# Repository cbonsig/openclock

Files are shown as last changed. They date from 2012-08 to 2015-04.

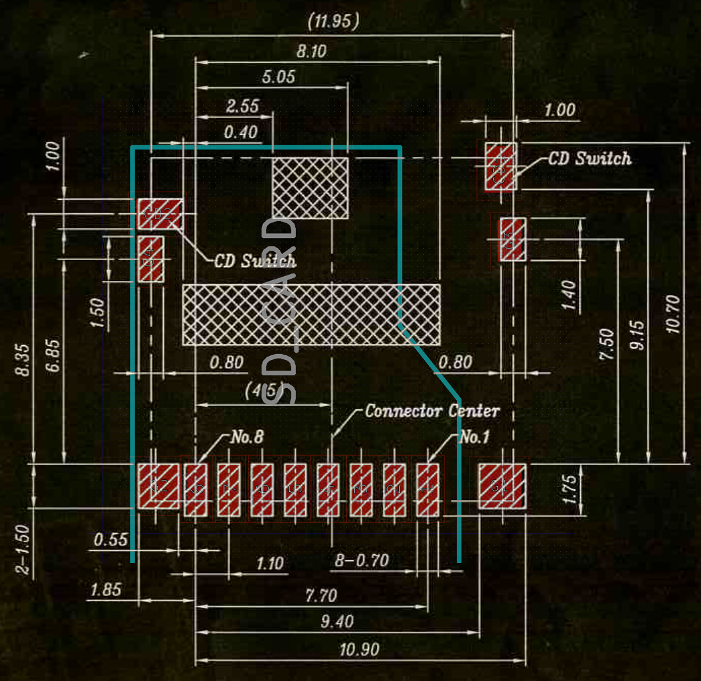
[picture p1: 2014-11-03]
kicad/Datasheets/U5 uSD_overlay.png

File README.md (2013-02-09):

openclock
=========

A clock designed to resolve the flaws of every annoying alarm clock that I've ever owned. Large display that can be easily read with uncorrected vision, adaptive brightness based on the time of day, intuitive touchscreen interface, clear feedback on the state of the alarm, intelligent alarm audio. Powered by Arduino. A work in progress. Journal of effort to date at http://clock.bonsignore.com

Open Clock Project by Craig Bonsignore is licensed under a Creative Commons Attribution-ShareAlike 3.0 United States License.Based on a work at http://clock.bonsignore.com.

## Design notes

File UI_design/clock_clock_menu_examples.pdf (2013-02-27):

P | M | A M | P | M | P M | 7: 0 | 0 | A | P | M | P | M | P | M | P | M
S U N | F E B | S U N | F E | B | S U N | F | E | B | S | U | N | F | E | B | S | U | N | F | E | B | S | U | N | F | E | B | S | U | N | F | E | B | S | U | N | F | E | B
P M | A M | A L A R M | A | M | A | L | A | R | M | A | M | A | L | A | R | M | A | M | A | L | A | R | M | A | M | A | L | A | R | M | A | M | A | L | A | R | M | A | M
5: 3 0 A | P | M | D | O | N | E | A | M | A | L | A | R | M | O | N | A | L | A | R | M | O | F | F | A | L | A | R | M | O | F | F | A | L | A | R | M | O | F | F
D | O | N | E | A | M | A | L | A | R | M | O | F | F | A | L | A | R | M | O | N | T | I | M | E | P | M | T | I | M | E | P | M
7: 0 | 0 | A | P | M | P | M | 7 | 0 | 0 | A | P | M | D | O | N | E | P | M | Y | E | A | R
P | M | M | O | N | T | H
D | O | N | E | D | A | Y

P M

open%clock%menu%examples%2013.02.26

the%alarm%time%is%
displayed%at%the%bottom%
left%whenever%the%alarm%
is%ON.%current%time%and%
alarm%time%are%clearly%
displayed,%so%it%is%
obvious%when%the%alarm%
is%set%correctly%(or%
incorrectly!)

let's%assume%you
probably%want%it
turned%on.%so%in%this
case,%alarm%is%changed
from%OFF%to%ON.

7: 0 0

⬇%tap%"done"

⬇%time%out
1 0: 4 4

if%you%bother%to

case%2:%check%alarm
1 0: 4 4

⬇%tap%screen
2 4

⬇%tap%screen%again
5: 3 0

2 4

⬇%time%out
1 0: 4 4

case%1:%show%date%(nite)
1 0: 4 4

⬇%tap%screen
2 4 | 2 4

check%the%alarm,%

a%single%tap%will%switch%
to%the%date%display,%
then%revert%to%the%time%
after%a%few%seconds.
2 4 | 2 4

case%2:%show%date%(day)
9: 2 0

⬇%tap%screen

1 0: 4 5

⬇%tap%screen | ⬇%tap%screen | ⬇%tap%screen | ⬇%tap%screen | ⬇%tap%screen

⬇"tap%"month"
2 4

⬇"tap%"done"

2 0 1 3

⬇"tap%"year"
0 2

⬇"tap%"alarm"
1 0: 4 4

⬇"tap%"time"

7: 0 0

⬇"tap%"alarm"
7: 0 0

case%7:%set%date
1 0: 4 4

⬇%tap%screen%again

2 4

1 1: 4 4

⬇"tap%"done"
1 1: 4 4

case%6:%set%time
1 0: 4 4

⬇%tap%screen%again

2 4

7: 0 0

⬇"tap%"alarm"
7: 0 0

1 0: 4 5

⬇"tap%"alarm"
1 0: 4 4

⬇"tap%digits

⬇"tap%"off"
7: 0 0

⬇"any%other%tap%/%timeout

7: 0 0

⬇"tap%"alarm"
7: 0 0

1 0: 4 5

case%5:%toggle%alarm%on
1 0: 4 4

⬇%tap%screen%again

⬇"tap%"on"
7: 0 0

⬇"any%other%tap%/%timeout

7: 0 0

⬇"tap%"alarm"
7: 0 0

case%4:%toggle%alarm%off
1 0: 4 4
⬇%time%out | ⬇%tap%screen%again
9: 2 0

from%7:00am%to%6:59pm%
("day"),%the%digits%are%
green.%from%7:00pm%to%
6:59am%("nite"),%the%
digits%are%red.%alarm%
digits%follow%the%same%
convention.

1 0: 4 5

after%first%digit%is%
tapped,%"alarm"%changes%
to%"done".%after%
clicking%"done",%turn%
alarm%ON,%and%return%to%
time%display.

In%alarm%set%mode,%
tapping%the%message%area%
instead%of%the%digits%
advances%to%toggle%mode.%
the%display%shows%"on"%
in%this%case.%touching%
"on"%toggles%alarm%to%
"off".%tapping%"off"%
will%toggle%back%to%
"on",%while%tapping%
anything%else%returns%to%
normal%time%display.

case%3:%set%alarm

In%alarm%toggle%mode,%
tapping%"alarm"%advances%
to%the%time%set%mode.%
this%behaves%the%same%as%
alarm%set,%where%"time"%
changes%to%"done"%when%
the%first%digit%is%
tapped.

shortcut:%in%normal%time%
display,%tap%the%alarm%
time%in%the%lower%left%
to%toggle%the%alarm%off.

Similar%behavior%for%
case%where%alarm%state%
is%initially%off.

shortcut:%in%normal%time%
display,%tap%the%empty%
spot%in%the%lower%left%
to%toggle%the%alarm%on.

The%date%is%set%using%a%
similar%approach.%The%
new%date%is%not%
committed%until%"done"%
is%tapped%on%the%final%
(day)%screen.

⬇%tap%digits%to%set

1 0: 4 4

⬇%tap%screen%again
5: 3 0

5: 3 1

⬇%first%tap%of%digit

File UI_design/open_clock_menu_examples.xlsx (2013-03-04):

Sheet: Feb26
case 1: show date (nite) |  |  |  |  |  |  | case 2: show date (day) |  |  |  |  |  |  | case 2: check alarm |  |  |  |  |  |  |  | case 3: set alarm |  |  |  |  |  |  |  | case 4: toggle alarm off |  |  |  |  |  |  |  | case 5: toggle alarm on |  |  |  |  |  |  |  | case 6: set time
1 |  | 0: | 4 |  | 4 |  |  |  | 9: | 2 |  | 0 |  | 1 |  | 0: |  | 4 |  | 4 |  | 1 |  | 0: |  | 4 |  | 4 |  | 1 |  | 0: |  | 4 |  | 4 |  | 1 |  | 0: |  | 4 |  | 4 |  | 1 |  | 0: |  | 4
 |  |  |  |  | P | M |  |  |  |  |  | A | M |  |  |  |  |  |  | P | M |  |  |  |  |  |  | P | M |  | 7: | 0 | 0 | A |  | P | M |  |  |  |  |  |  | P | M
⬇ tap screen |  |  |  |  |  |  | ⬇ tap screen |  |  |  |  |  |  | ⬇ tap screen |  |  |  |  |  |  |  | ⬇ tap screen |  |  |  |  |  |  |  | ⬇ tap screen |  |  |  |  |  |  |  | ⬇ tap screen |  |  |  |  |  |  |  | ⬇ tap screen
 |  |  | 2 |  | 4 |  |  |  |  | 2 |  | 4 |  |  |  |  |  | 2 |  | 4 |  |  |  |  |  | 2 |  | 4 |  |  |  |  |  | 2 |  | 4 |  |  |  |  |  | 2 |  | 4 |  |  |  |  |  | 2
S | U | N |  | F | E | B | S | U | N |  | F | E | B | S | U | N |  |  | F | E | B | S | U | N |  |  | F | E | B | S | U | N |  |  | F | E | B | S | U | N |  |  | F | E | B | S | U | N
⬇ time out |  |  |  |  |  |  | ⬇ time out |  |  |  |  |  |  | ⬇ tap screen again |  |  |  |  |  |  |  | ⬇ tap screen again |  |  |  |  |  |  |  | ⬇ tap screen again |  |  |  |  |  |  |  | ⬇ tap screen again |  |  |  |  |  |  |  | ⬇ tap screen again
1 |  | 0: | 4 |  | 4 |  |  |  | 9: | 2 |  | 0 |  |  |  | 5: |  | 3 |  | 0 |  |  |  | 5: |  | 3 |  | 0 |  |  |  | 7: |  | 0 |  | 0 |  |  |  | 7: |  | 0 |  | 0 |  |  |  | 7: |  | 0
 |  |  |  |  | P | M |  |  |  |  |  | A | M | A | L | A | R | M |  | A | M | A | L | A | R | M |  | A | M | A | L | A | R | M |  | A | M | A | L | A | R | M |  | A | M | A | L | A | R | M
a single tap will switch to the date display, then revert to the time after a few seconds. |  |  |  |  |  |  | from 7:00am to 6:59pm ("day"), the digits are green. from 7:00pm to 6:59am ("nite"), the digits are red. alarm digits follow the same convention. |  |  |  |  |  |  | ⬇ time out |  |  |  |  |  |  |  | ⬇ first tap of digit |  |  |  |  |  |  |  | ⬇ tap "alarm" |  |  |  |  |  |  |  | ⬇ tap "alarm" |  |  |  |  |  |  |  | ⬇ tap "alarm"
 |  |  |  |  |  |  |  |  |  |  |  |  |  | 1 |  | 0: |  | 4 |  | 4 |  |  |  | 5: |  | 3 |  | 1 |  |  |  | 7: |  | 0 |  | 0 |  |  |  | 7: |  | 0 |  | 0 |  |  |  | 7: |  | 0
 |  |  |  |  |  |  |  |  |  |  |  |  |  |  | 5: | 3 | 0 | A |  | P | M | D | O | N | E |  |  | A | M | A | L | A | R | M |  | O | N | A | L | A | R | M | O | F | F | A | L | A | R | M
 |  |  |  |  |  |  |  |  |  |  |  |  |  | if you bother to |  |  |  |  |  |  |  | ⬇ tap digits to set |  |  |  |  |  |  |  | ⬇ tap "on" |  |  |  |  |  |  |  | ⬇ tap "off" |  |  |  |  |  |  |  | ⬇ tap "alarm"
 |  |  |  |  |  |  |  |  |  |  |  |  |  | check the alarm,
 |  |  |  |  |  |  |  |  |  |  |  |  |  | let's assume you |  |  |  |  |  |  |  |  |  | 7: |  | 0 |  | 0 |  |  |  | 7: |  | 0 |  | 0 |  |  |  | 7: |  | 0 |  | 0 |  | 1 |  | 0: |  | 4
 |  |  |  |  |  |  |  |  |  |  |  |  |  | probably want it
 |  |  |  |  |  |  |  |  |  |  |  |  |  | turned on. so in this
 |  |  |  |  |  |  |  |  |  |  |  |  |  | case, alarm is changed |  |  |  |  |  |  |  | D | O | N | E |  |  | A | M | A | L | A | R | M | O | F | F | A | L | A | R | M |  | O | N | T | I | M | E
 |  |  |  |  |  |  |  |  |  |  |  |  |  | from OFF to ON.
 |  |  |  |  |  |  |  |  |  |  |  |  |  |  |  |  |  |  |  |  |  | ⬇ tap "done" |  |  |  |  |  |  |  | ⬇ any other tap / timeout |  |  |  |  |  |  |  | ⬇ any other tap / timeout |  |  |  |  |  |  |  | ⬇ tap digits
 |  |  |  |  |  |  |  |  |  |  |  |  |  | the alarm time is displayed at the bottom left whenever the alarm is ON. current time and alarm time are clearly displayed, so it is obvious when the alarm is set correctly (or incorrectly!)
 |  |  |  |  |  |  |  |  |  |  |  |  |  |  |  |  |  |  |  |  |  | 1 |  | 0: |  | 4 |  | 5 |  | 1 |  | 0: |  | 4 |  | 5 |  | 1 |  | 0: |  | 4 |  | 5 |  | 1 |  | 1: |  | 4
 |  |  |  |  |  |  |  |  |  |  |  |  |  |  |  |  |  |  |  |  |  |  | 7: | 0 | 0 | A |  | P | M |  |  |  |  |  |  | P | M |  | 7: | 0 | 0 | A |  | P | M | D | O | N | E
 |  |  |  |  |  |  |  |  |  |  |  |  |  |  |  |  |  |  |  |  |  | after first digit is tapped, "alarm" changes to "done". after clicking "done", turn alarm ON, and return to time display. |  |  |  |  |  |  |  | In alarm set mode, tapping the message area instead of the digits advances to toggle mode. the display shows "on" in this case. touching "on" toggles alarm to "off". tapping "off" will toggle back to "on", while tapping anything else returns to normal time display. |  |  |  |  |  |  |  | Similar behavior for case where alarm state is initially off. |  |  |  |  |  |  |  | ⬇ tap "done"
 |  |  |  |  |  |  |  |  |  |  |  |  |  |  |  |  |  |  |  |  |  |  |  |  |  |  |  |  |  |  |  |  |  |  |  |  |  |  |  |  |  |  |  |  |  | 1 |  | 1: |  | 4
 |  |  |  |  |  |  |  |  |  |  |  |  |  |  |  |  |  |  |  |  |  |  |  |  |  |  |  |  |  |  |  |  |  |  |  |  |  | shortcut: in normal time display, tap the empty spot in the lower left to toggle the alarm on.
 |  |  |  |  |  |  |  |  |  |  |  |  |  |  |  |  |  |  |  |  |  |  |  |  |  |  |  |  |  |  |  |  |  |  |  |  |  |  |  |  |  |  |  |  |  | In alarm toggle mode, tapping "alarm" advances to the time set mode. this behaves the same as alarm set, where "time" changes to "done" when the first digit is tapped.
 |  |  |  |  |  |  |  |  |  |  |  |  |  |  |  |  |  |  |  |  |  |  |  |  |  |  |  |  |  | shortcut: in normal time display, tap the alarm time in the lower left to toggle the alarm off.
open clock menu examples 2013.02.26

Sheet: Mar3
0 | 1 |  | 0: |  | 4 |  | 4
 |  |  |  |  |  |  | P | M
 | ⬇ tap screen
10 |  |  |  |  | 2 |  | 4
 | S | U | N |  |  | F | E | B
 | ⬇ tap screen
20 | < |  |  |  |  |  | > |  | 201 |  |  | 7: |  | 0 |  | 0 |  | 0 | 1 |  | 0: |  | 4 | 4
 | A | L | A | R | M | S | E | T |  | D | O | N | E |  |  | A | M |  |  | 5: | 3 | 0 | A | P | M
 | ⬇ tap >
30 | < |  |  |  |  |  | > |  | 40 | < |  |  |  |  |  | >
 | S | O | U | N | D | O | F | F |  | S | O | U | N | D |  | O | N |  |  |  |  |  |  |  |  |  |  | change code for this new menu scheme
 |  |  |  |  |  |  |  |  |  |  |  |  |  |  |  |  |  |  |  |  |  |  |  |  |  |  |  | change display/render scheme to allow for non-digits in hr/min area
 | ⬇ tap >
40 | < |  |  |  |  |  | > |  | 30 | < |  |  |  |  |  | >
 | S | O | U | N | D |  | O | N |  | S | O | U | N | D | O | F | F
 | ⬇ tap >
50 | < |  |  |  |  |  | > |  | 501 | 1 |  | 1: |  | 4 |  | 5 |  | 0 | 1 |  | 1: |  | 4 | 5
 | T | I | M | E |  | S | E | T |  | D | O | N | E |  |  | P | M |  |  |  |  |  |  | P | M
 | ⬇ tap >
60 | < |  |  |  |  |  | > |  | 601 | 2 |  | 0 |  | 1 |  | 3 |  | 602 |  |  |  |  | 0 | 3 |  | 603 |  |  |  | 0 |  | 4 |  | 0 | 1 | 0: | 4 | 4
 | D | A | T | E |  | S | E | T |  | Y | E | A | R |  |  | > | > |  | M | O | N | T | H | > | > |  | D | A | Y | D | O | N | E |  |  |  |  | P | M
 | ⬇ tap >
99 | < |  |  |  |  |  | >
 | E | X | I | T
 | ⬇ tap >
0 | 1 |  | 0: |  | 4 |  | 4
 |  |  |  |  |  |  | P | M
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

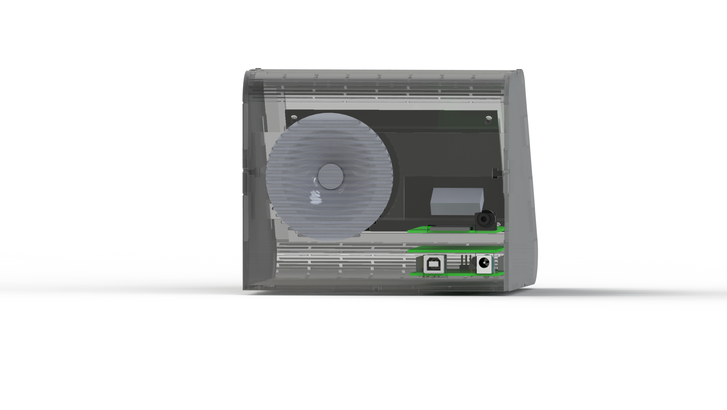
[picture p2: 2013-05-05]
enclosure_design/2D_rev2/clear_rendered_back.png

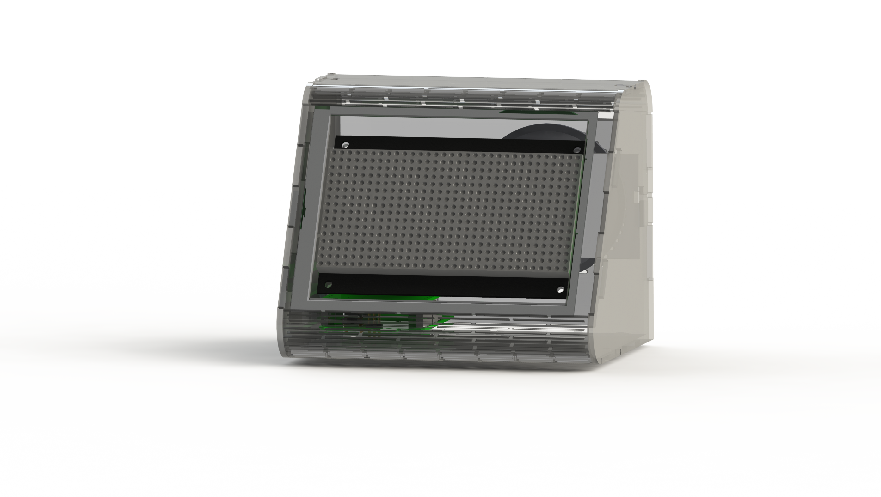
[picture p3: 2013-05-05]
enclosure_design/2D_rev2/clear_rendered.png

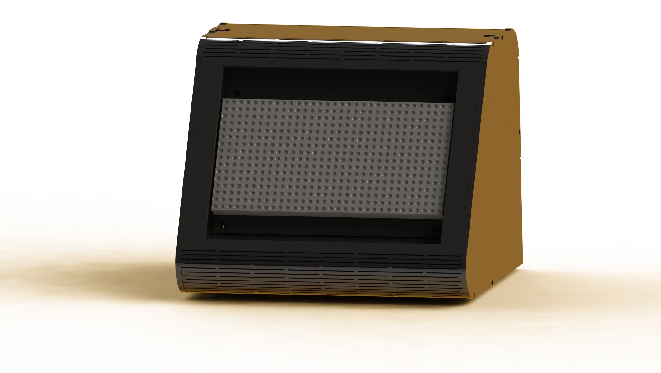
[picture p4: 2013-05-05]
enclosure_design/2D_rev2/black_rendered_front.png

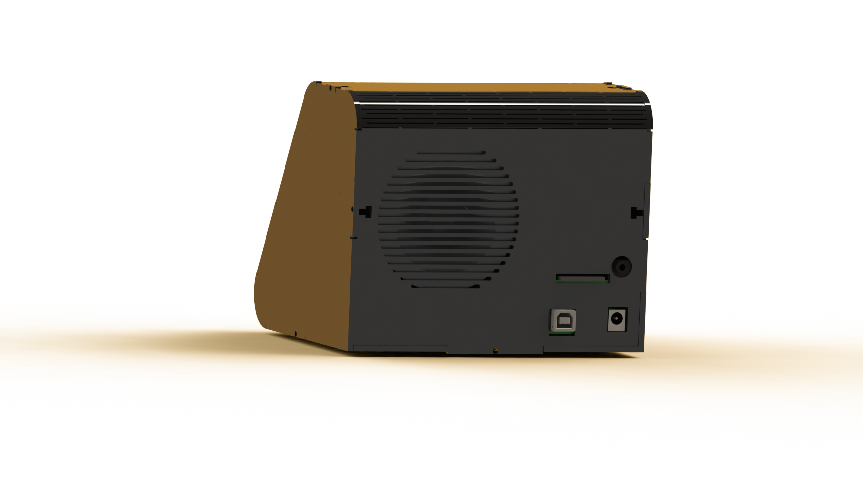
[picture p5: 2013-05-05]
enclosure_design/2D_rev2/black_rendered_back.png

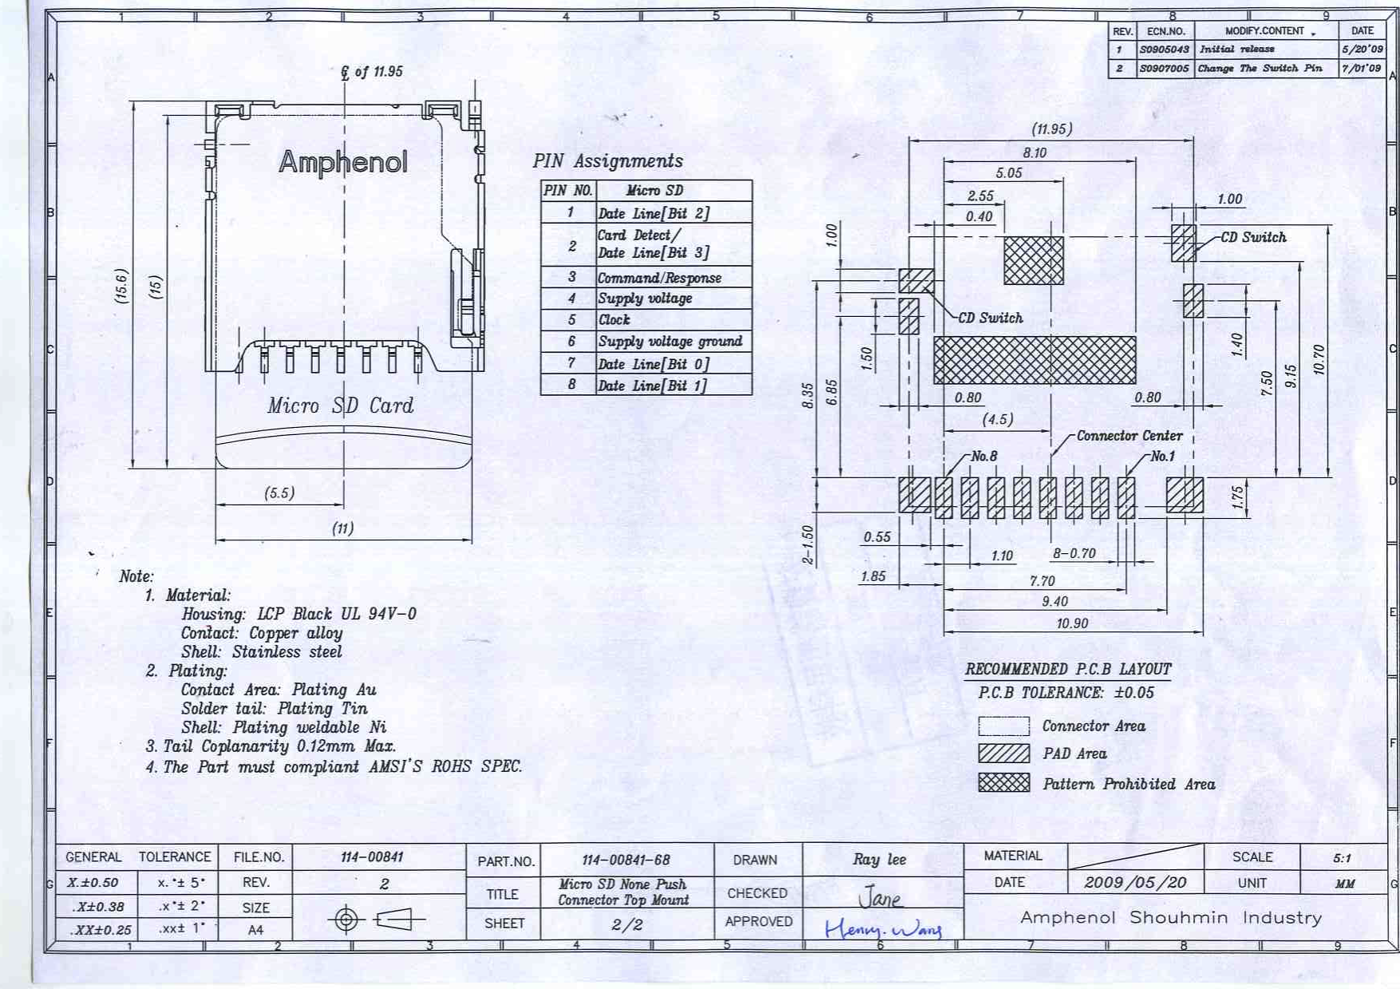
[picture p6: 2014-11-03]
kicad/Datasheets/U5 114-00841-68 uSD.png

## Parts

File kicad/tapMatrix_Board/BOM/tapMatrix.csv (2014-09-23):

Id | Designator | Package | Quantity | Designation | Supplier and ref
1 | C1,C2,C3,C5,C7 | Capacitors_SMD:c_0603 | 5 | 0.1uF
2 | C8 | Capacitors_SMD:c_0603 | 1 | 0.01uF
3 | IC1 | Housings_SOIC:SOIC-8_N | 1 | DS1307
4 | JP1 | Pin_Headers:Pin_Header_Straight_1x06 | 1 | 6_PIN_1
5 | JP2 | Pin_Headers:Pin_Header_Straight_1x06 | 1 | 6_PIN_2
6 | JP3 | Pin_Headers:Pin_Header_Straight_1x08 | 1 | 8_PIN_1
7 | JP4 | Pin_Headers:Pin_Header_Straight_1x08 | 1 | 8_PIN_2
8 | JP6 | Pin_Headers:Pin_Header_Straight_1x02 | 1 | SPKR
9 | R1,R2 | Resistors_SMD:R_0603 | 2 | R
10 | R3 | Resistors_SMD:R_0603 | 1 | 100K
11 | R4 | Resistors_SMD:R_0603 | 1 | 1.5K
12 | R5 | Resistors_SMD:R_0603 | 1 | 10K
13 | U2 | SMD_Packages:SOIC-8-N | 1 | MCP4921-E/SN
14 | BT1 | tapmatrix:CR2032 | 1 | BATTERY
15 | P6 | tapmatrix:5103310--3 | 1 | LED_MATRIX_HDR
16 | P5 | tapmatrix:SFW4R-5STE1LF | 1 | TS_ZIF
17 | U5 | tapmatrix:114-00841-68 | 1 | SD_CARD
18 | C4,C6,C9 | Capacitors_Tantalum_SMD:TantalC_SizeC_EIA-6032_Reflow | 3 | 100uF/6V
19 | JP5 | Pin_Headers:Pin_Header_Straight_1x04 | 1 | 4_PIN_1
20 | U3 | SMD_Packages:SOIC-14_N | 1 | 74LS125
21 | U1 | Housings_SOT-89:SOT89-3_Housing | 1 | MCP1700T-3302E/MB
22 | U4 | Housings_SOIC:SOIC-8_N | 1 | TL072

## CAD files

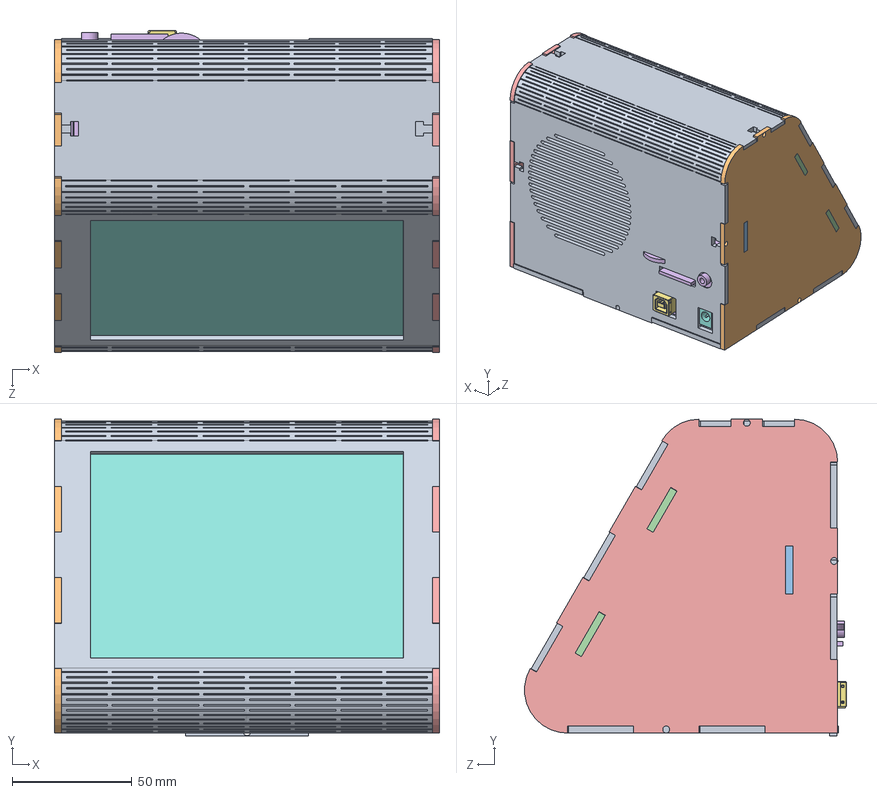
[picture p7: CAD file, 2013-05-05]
enclosure_design/2D_rev2/Enclosure_Assembly.SLDASM
161.0 x 132.4 x 134.5 mm
Combine1
Cut-Extrude24
uno-pcb x 2
SW3dPS-67068-0000-molex
RAPC732
3x2-100 x 2
C-0534237-04-3 x 2
C-0534237-06-3 x 2
28pdipskt
User Library-28 pin dip
wave_shield
SureElectronics_32x16_DE-DP14112
Fujitsu_4wire_6.4in_N010-0554-T048
3in_speaker

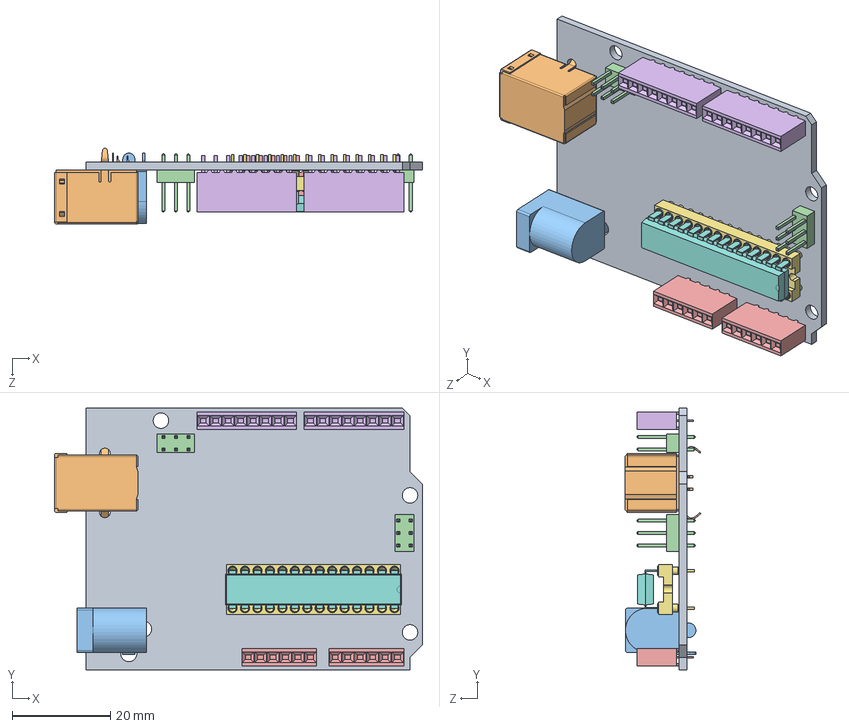
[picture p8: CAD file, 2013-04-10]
enclosure_design/2D_rev2/uno-assy/uno-assy.SLDASM
75.0 x 53.3 x 15.4 mm
uno-pcb
SW3dPS-67068-0000-molex
RAPC732
3x2-100 x 2
C-0534237-04-3 x 2
C-0534237-06-3 x 2
28pdipskt
User Library-28 pin dip

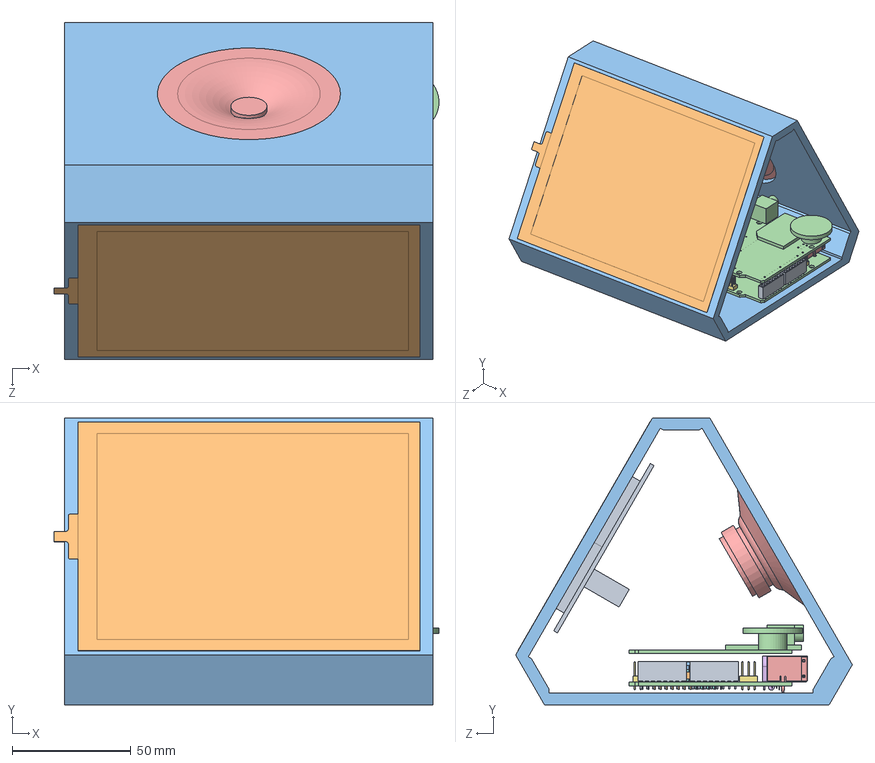
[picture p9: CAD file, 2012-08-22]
enclosure_design/3D_rev1/Open_Clock.SLDASM
161.9 x 120.6 x 141.6 mm
SureElectronics_32x16_DE-DP14112
Fujitsu_4wire_6.4in_N010-0554-T048
base
uno-pcb
SW3dPS-67068-0000-molex
RAPC732
3x2-100 x 2
C-0534237-04-3 x 2
C-0534237-06-3 x 2
28pdipskt
User Library-28 pin dip
wave_shield
3in_speaker

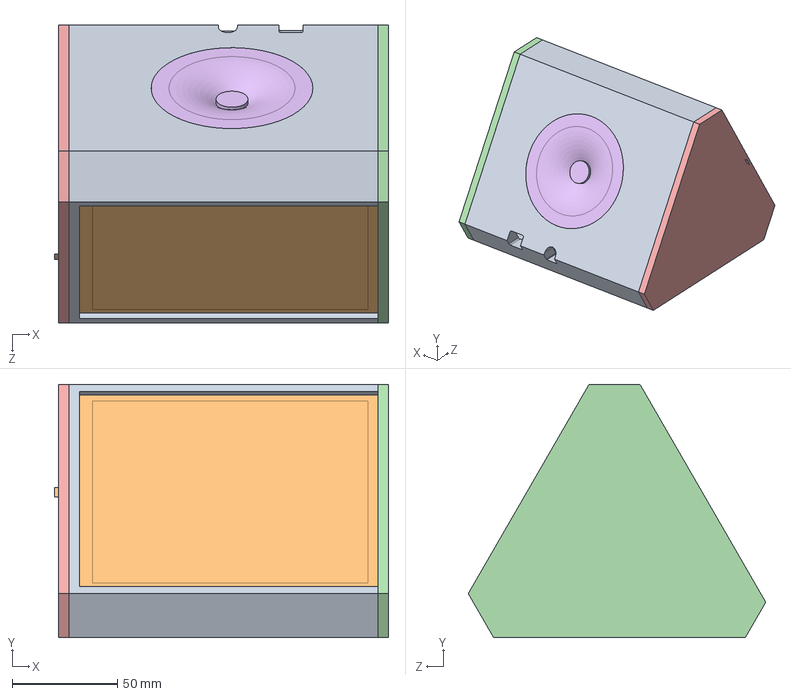
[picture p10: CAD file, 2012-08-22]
enclosure_design/3D_rev1/Open_Clock_2.SLDASM
159.0 x 120.6 x 141.6 mm
base_plus_walls
Fujitsu_4wire_6.4in_N010-0554-T048
SureElectronics_32x16_DE-DP14112
right_cap
left_cap
uno-pcb
SW3dPS-67068-0000-molex
RAPC732
3x2-100 x 2
C-0534237-04-3 x 2
C-0534237-06-3 x 2
28pdipskt
User Library-28 pin dip
3in_speaker
wave_shield

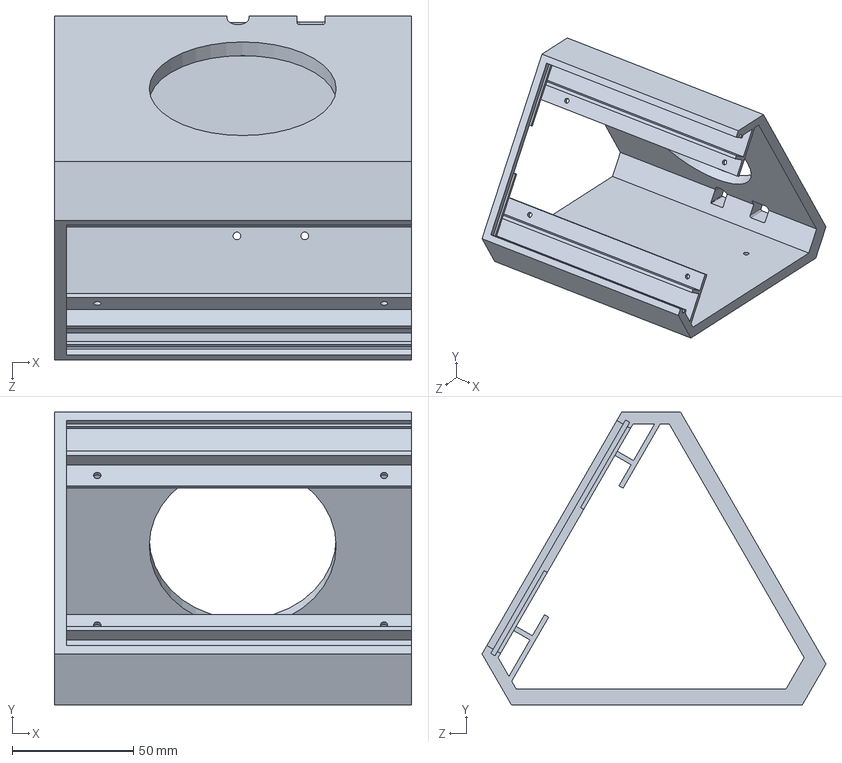
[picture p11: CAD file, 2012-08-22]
enclosure_design/3D_rev1/base_plus_walls.SLDPRT
147.0 x 120.6 x 141.6 mm

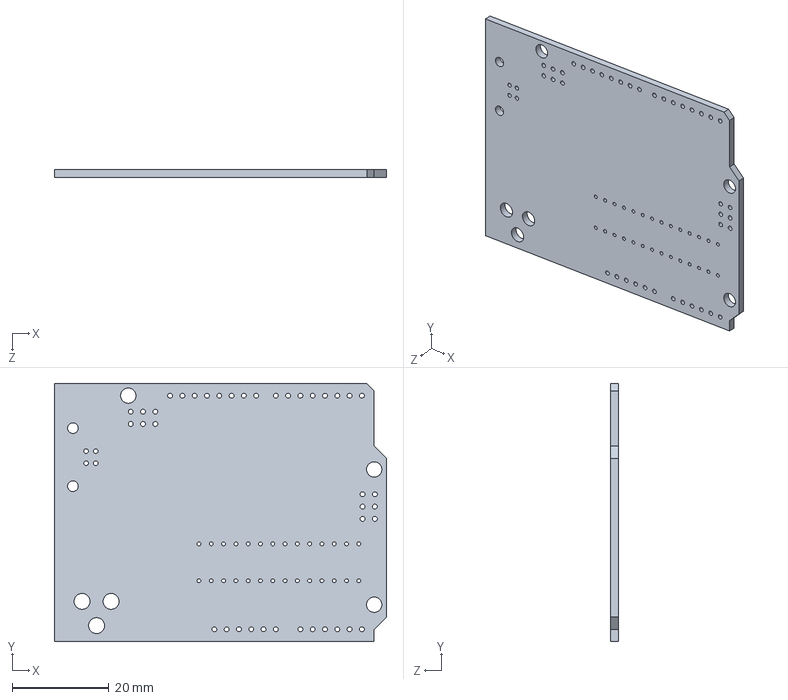
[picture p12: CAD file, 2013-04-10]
enclosure_design/2D_rev2/uno-assy/uno-pcb.SLDPRT
68.6 x 53.3 x 1.59 mm

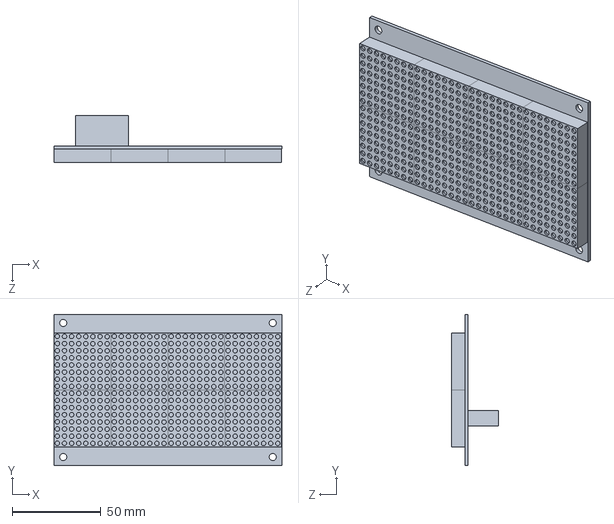
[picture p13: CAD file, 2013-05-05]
enclosure_design/2D_rev2/SureElectronics_32x16_DE-DP14112.SLDPRT
128.3 x 85.1 x 26.3 mm

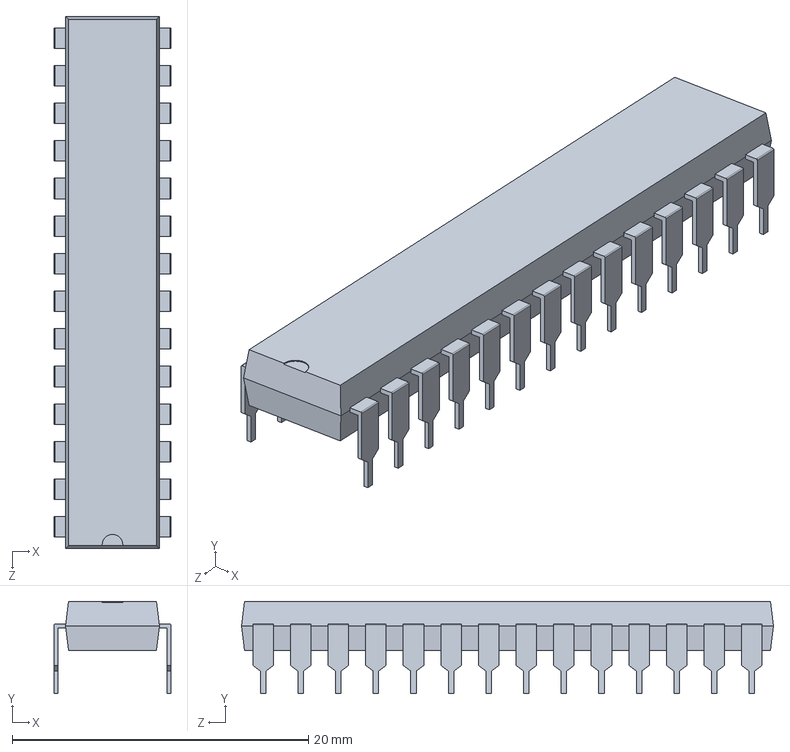
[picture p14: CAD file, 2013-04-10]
enclosure_design/2D_rev2/uno-assy/User Library-28 pin dip.SLDPRT
7.87 x 6.22 x 35.9 mm

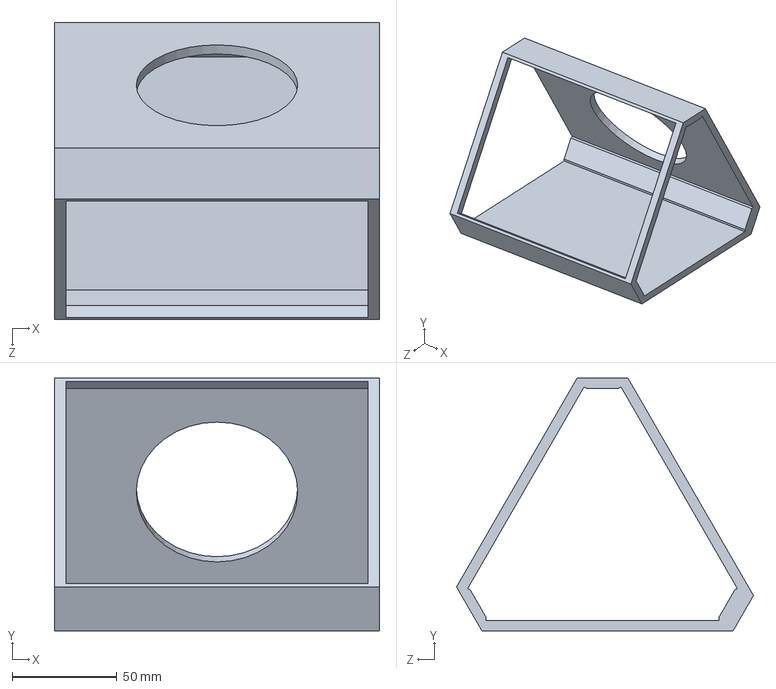
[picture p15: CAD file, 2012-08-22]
enclosure_design/3D_rev1/base.SLDPRT
155.0 x 120.6 x 141.6 mm

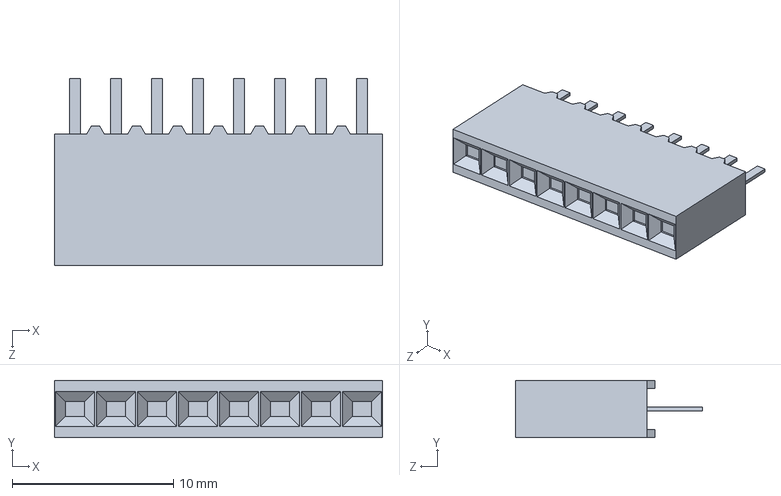
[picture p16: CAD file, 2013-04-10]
enclosure_design/2D_rev2/uno-assy/C-0534237-06-3.SLDPRT
20.3 x 3.56 x 11.6 mm

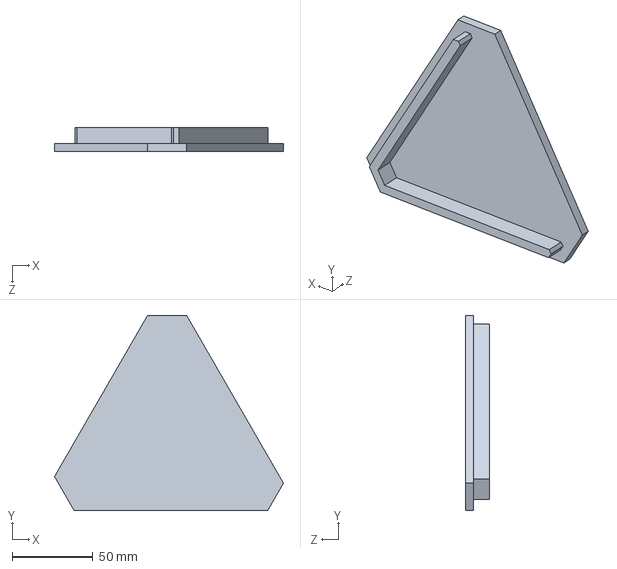
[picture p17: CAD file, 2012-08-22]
enclosure_design/3D_rev1/right_cap.sldprt
141.6 x 120.6 x 15.0 mm

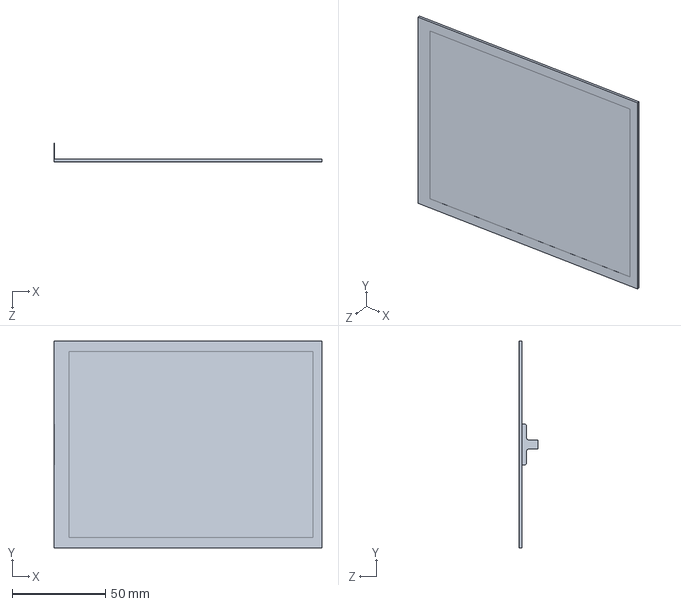
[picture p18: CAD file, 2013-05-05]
enclosure_design/2D_rev2/Fujitsu_4wire_6.4in_N010-0554-T048.SLDPRT
144.0 x 111.0 x 10.0 mm

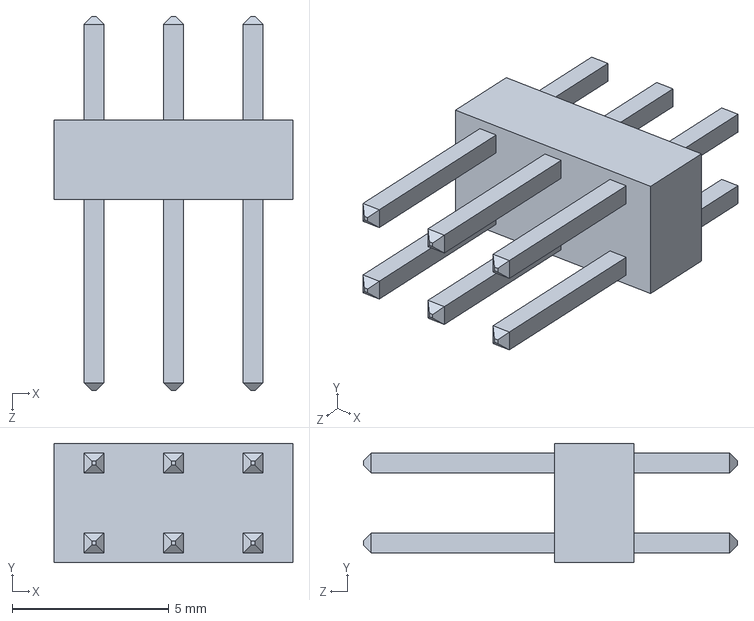
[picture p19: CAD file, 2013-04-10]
enclosure_design/2D_rev2/uno-assy/3x2-100.SLDPRT
7.62 x 3.81 x 11.9 mm

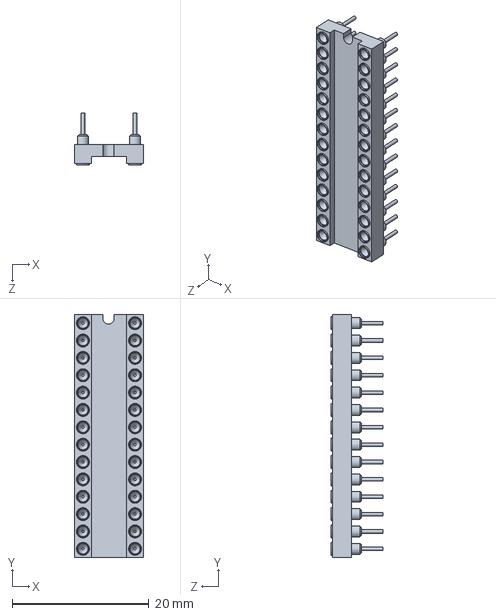
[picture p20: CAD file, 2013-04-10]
enclosure_design/2D_rev2/uno-assy/28pdipskt.SLDPRT
10.2 x 35.6 x 7.62 mm

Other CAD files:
enclosure_design/2D_rev2/Body4.sldprt
enclosure_design/2D_rev2/Cut-Extrude24.sldprt
enclosure_design/3D_rev1/left_cap.sldprt
enclosure_design/2D_rev2/Body5.sldprt
enclosure_design/2D_rev1/Fujitsu_4wire_6.4in_N010-0554-T048.SLDPRT
enclosure_design/2D_rev1/SureElectronics_32x16_DE-DP14112.SLDPRT
enclosure_design/2D_rev1/box1-1-bottom.sldprt
enclosure_design/2D_rev1/box1-2-top.sldprt
enclosure_design/2D_rev1/box1-3-left.sldprt
enclosure_design/2D_rev1/box1-4-right.sldprt
enclosure_design/2D_rev1/box1-5-front.sldprt
enclosure_design/2D_rev1/box1-6-back.sldprt
enclosure_design/2D_rev1/box1-8-mid-front.sldprt
enclosure_design/2D_rev1/box1-assembly.SLDDRW
enclosure_design/2D_rev1/box1-assembly.sldasm
enclosure_design/2D_rev1/box1-mid-back.sldprt
enclosure_design/2D_rev1/p3_inkscape_box_2013_04_07_components.dxf
enclosure_design/2D_rev1/p3_inkscape_box_2013_04_07_laseronly.dxf
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

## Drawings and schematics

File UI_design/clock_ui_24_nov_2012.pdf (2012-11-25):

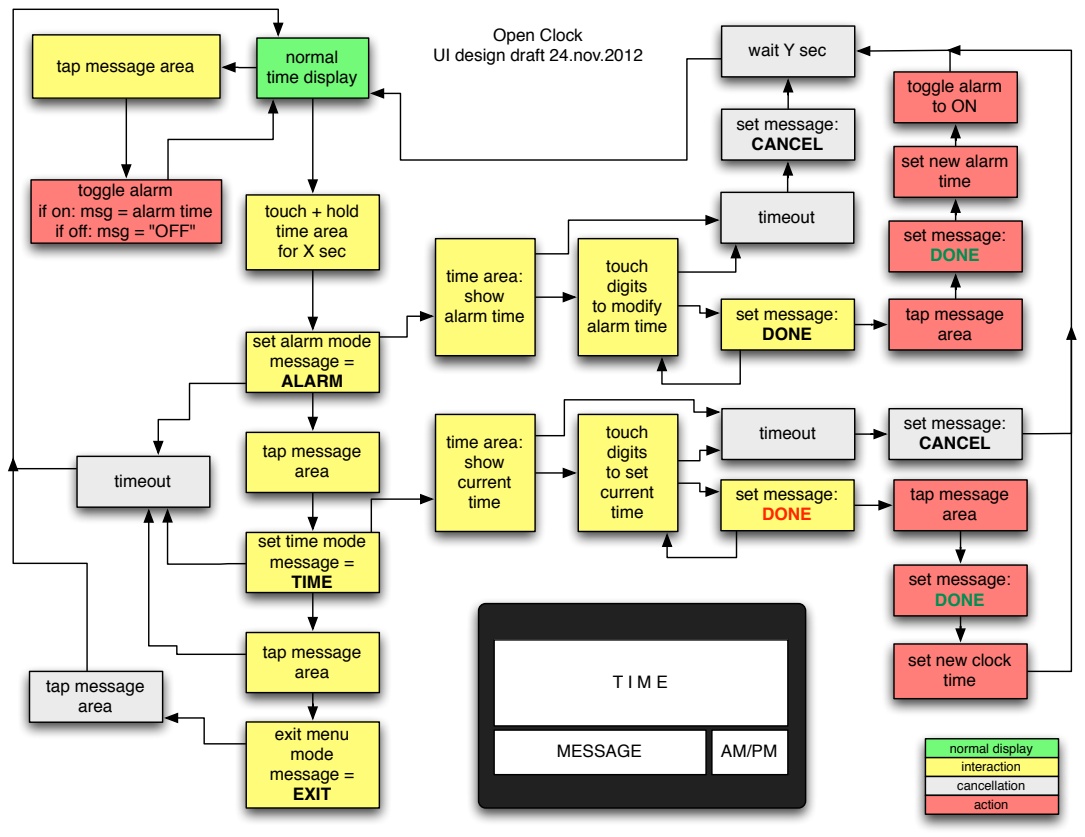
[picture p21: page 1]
normal time display; touch + hold time area for X sec; tap message area; exit menu mode message = EXIT; touch digits to modify alarm time; touch digits to set current time; MESSAGE; tap message; area; timeout; toggle alarm to ON; set message: DONE; set message: CANCEL; wait Y sec; time area: show alarm time; time area: show current time; Open Clock; normal display interaction cancellation action

UI design draft 24.nov.2012

tap message area

set new alarm
time

toggle alarm
if on: msg = alarm time
if off: msg = "OFF"

set alarm mode
message =
ALARM

set time mode
TIME

set new clock

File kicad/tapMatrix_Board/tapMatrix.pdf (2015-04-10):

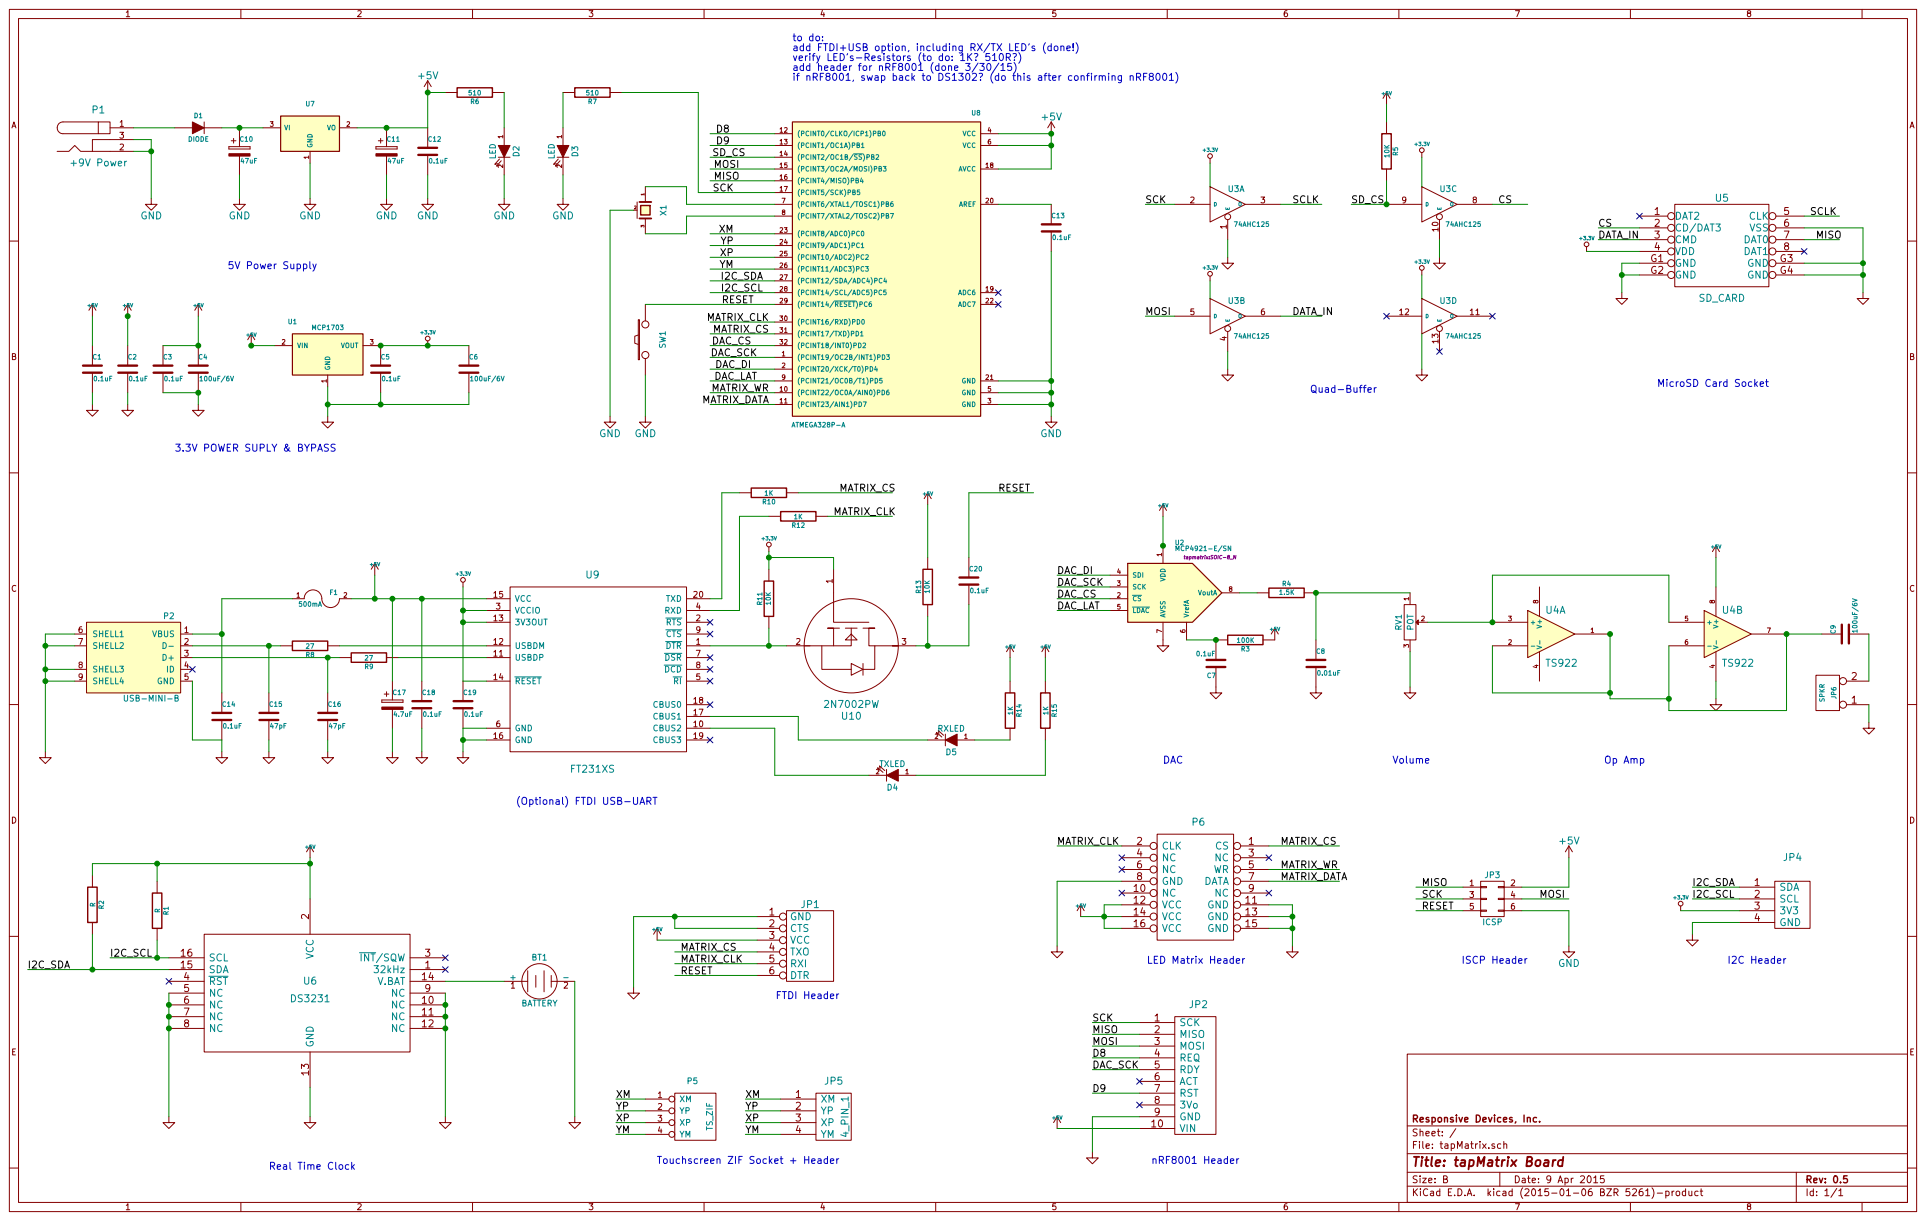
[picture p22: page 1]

to do: add FTDI+USB option, including RX/TX LEDs (done!)
verify LEDs-Resistors (to do: 1K? 510R?)
add header for nRF8001 (done 3/30/15)
if nRF8001, swap back to DS1302? (do this after confirming nRF8001)
D8 D9 MATRIX_CS

(Optional) FTDI USB-UART

Id: 1/1 Title: tapMatrix Board

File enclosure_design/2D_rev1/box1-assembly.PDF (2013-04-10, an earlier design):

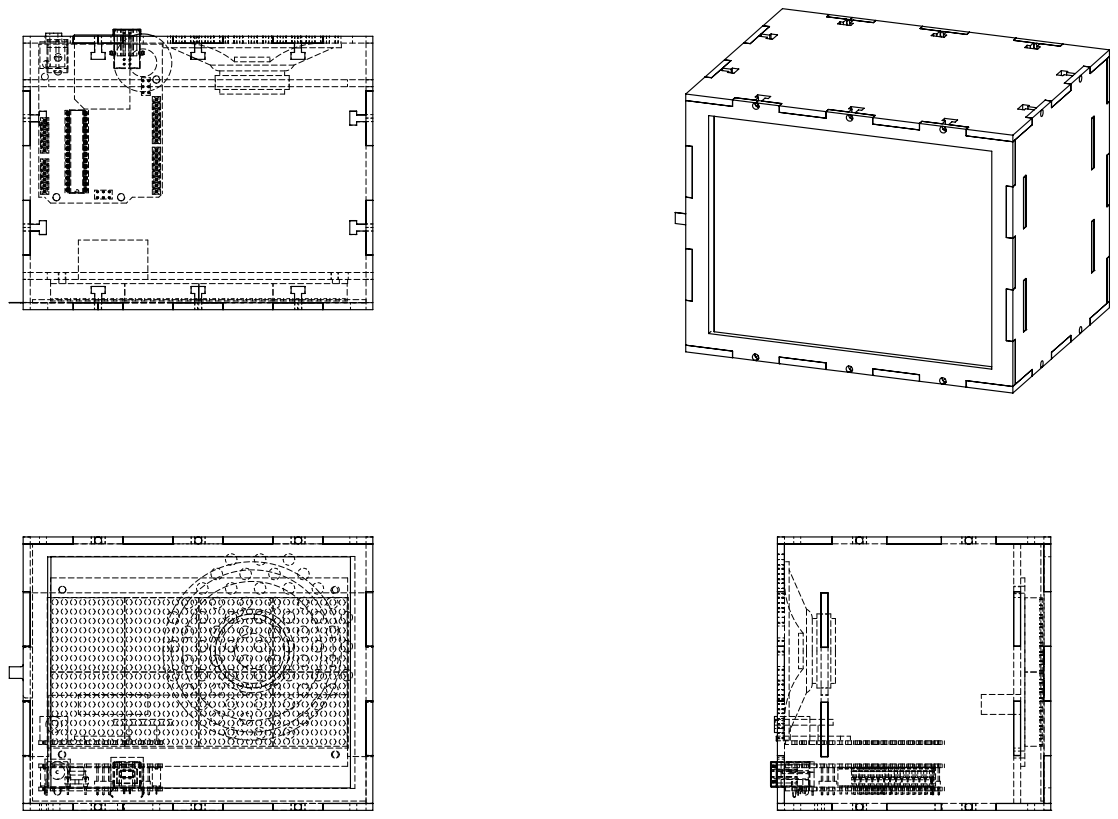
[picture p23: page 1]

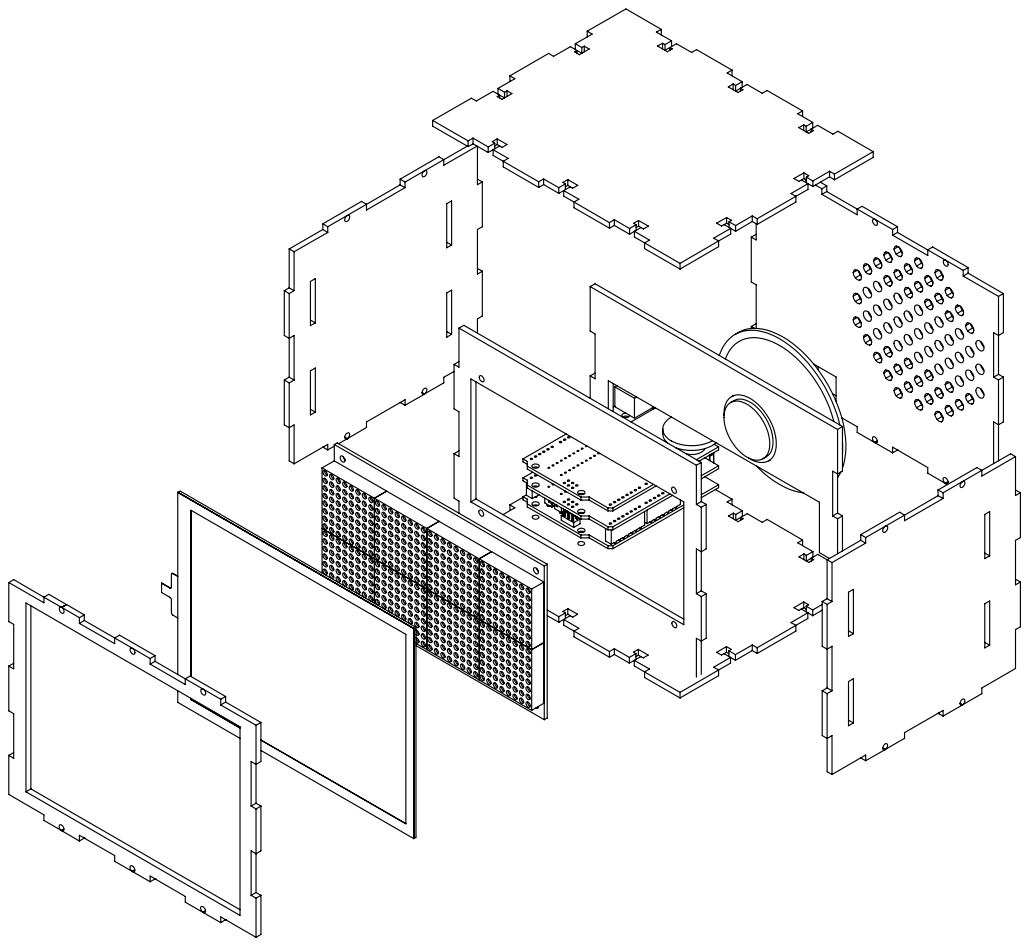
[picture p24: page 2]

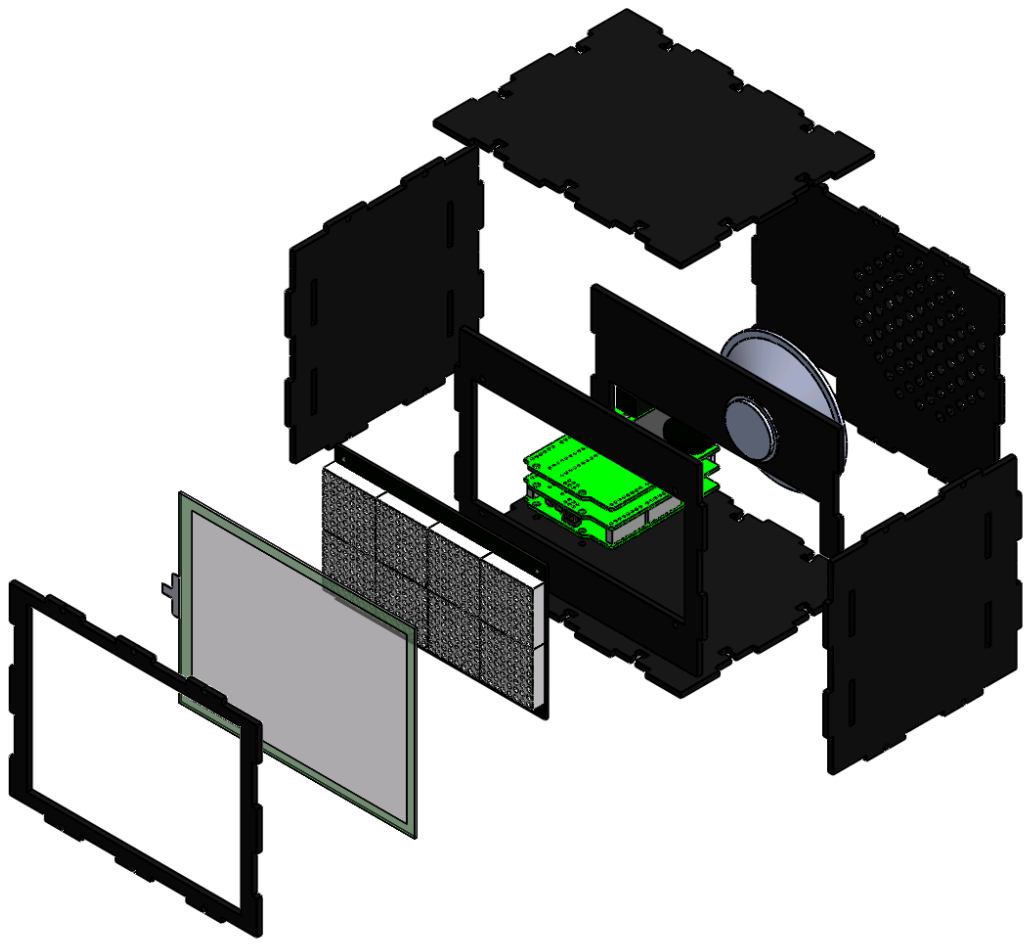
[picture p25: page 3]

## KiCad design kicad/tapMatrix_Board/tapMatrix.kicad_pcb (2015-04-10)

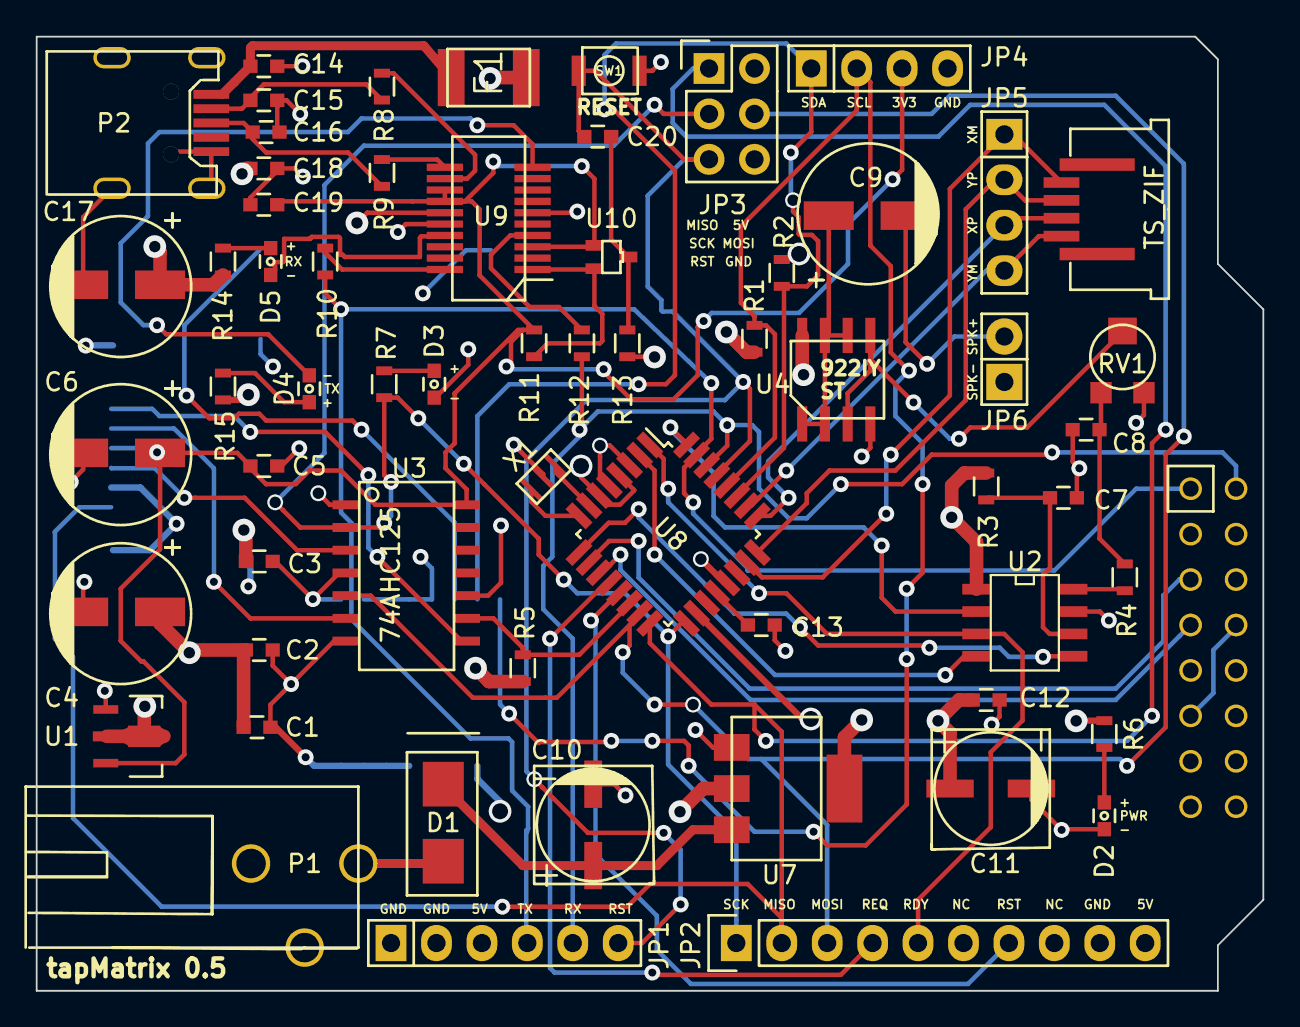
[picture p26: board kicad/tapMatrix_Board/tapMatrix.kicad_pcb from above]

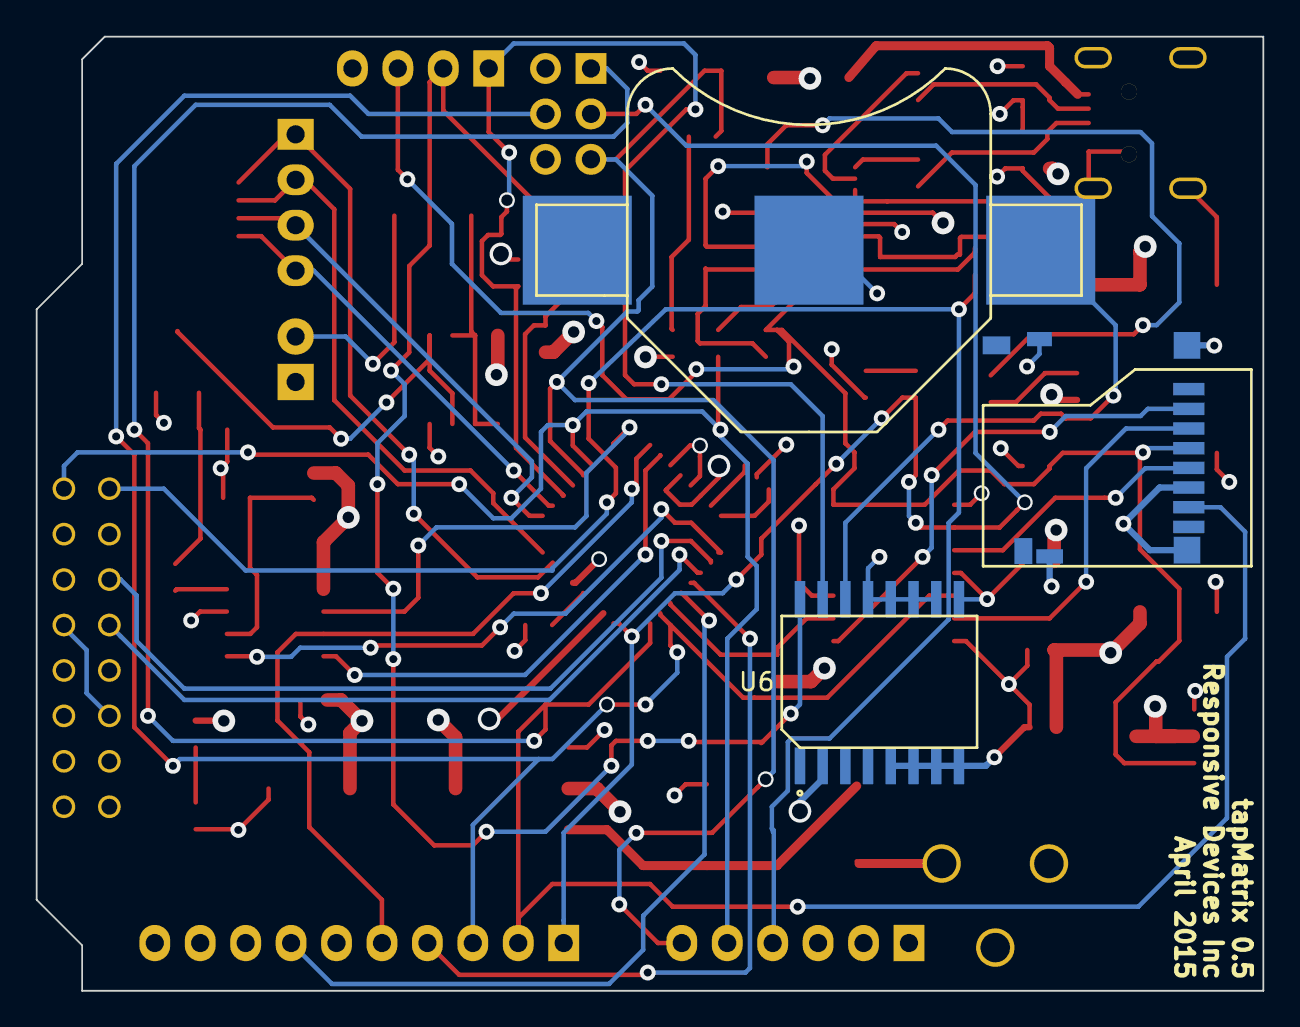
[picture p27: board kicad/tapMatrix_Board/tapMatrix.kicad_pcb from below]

Board: 4 copper layers, 68.6 x 53.3 mm, 65 parts (3 on the bottom side), 54 nets.

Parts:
BT1: BATTERY; CR2032
C1, C2, C3, C5, C7, C12, C13, C14, C18, C19, C20: 0.1uF; C_0603
C4, C6, C9: 100uF/6V; EEE-0JA101WR
C8: 0.01uF; C_0603
C10, C11: 47uF; CAP_MVA_F55
C15, C16: 47pF; C_0603
C17: 4.7uF; EEE-0JA101WR
D1: DIODE; DS16004
D2, D3: LED; D_0603
D4: TXLED; D_0603
D5: RXLED; D_0603
F1: 500mA; Fuse_MF_MSMF
JP1: FTDI; Pin_Header_Straight_1x06
JP2: nRF8001; Pin_Header_Straight_1x10
JP3: ICSP; Pin_Header_Straight_2x03
JP4: 4_PIN_2; Pin_Header_Straight_1x04
JP5: 4_PIN_1; Pin_Header_Straight_1x04
JP6: SPKR; Pin_Header_Straight_1x02
P1: +9V Power; PJ-102AH
P2: USB-MINI-B; USBMiniB_UX60_MB_5S8
P5: TS_ZIF; SFW4R­5STE1LF
P6: LED_MATRIX_HDR; 5103310­-3
R1, R2: R; R_0603
R3: 100K; R_0603
R4: 1.5K; R_0603
R5, R11, R13: 10K; R_0603
R6, R7: 510; R_0603
R8, R9: 27; R_0603
R10, R12, R14, R15: 1K; R_0603
RESET: SW_PUSH; SW_3BU_1000P
RV1: POT; TC33X
U1: MCP1703; SOT89-3_Housing
U2: MCP4921-E/SN; SOIC-8_N
U3: 74AHC125; SO-14
U4: TS922; TS922_SO8
U5: SD_CARD; 114-00841-68
U6: DS3231
U7: NCP1117ST50T3G; SOT223_318H
U8: ATMEGA328P-A; TQFP-32_7x7mm_Pitch0.8mm
U9: FT231XS; SSOP20_FTDI231X
U10: 2N7002PW; SOT-323
X1: CRYSTAL_SMD; XTAL_CSTCE_V

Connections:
+5V: C1.1, C2.1, C3.1, C4.1, C11.1, C12.1, C17.1, C18.1, F1.2, JP1.3, JP2.10, JP3.2, P6.12, P6.14, P6.16, R1.1, R2.1, R3.1, R5.1, R6.1, R13.1, R14.2, R15.2, U1.2, U2.1, U4.8, U6.2, U7.2, U8.4, U8.6, U8.18, U9.15
/CS: U3.8, U5.2
/D8: JP2.4, U8.12
/D9: JP2.7, U8.13
/DAC_CS: U2.2, U8.32
/DAC_DI: U2.4, U8.2
/DAC_LAT: U2.5, U8.9
/DAC_SCK: JP2.5, U2.3, U8.1
/DATA_IN: U3.6, U5.3
/I2C_SCL: JP4.2, R1.2, U6.16, U8.28
/I2C_SDA: JP4.1, R2.2, U6.15, U8.27
/MATRIX_CLK: JP1.5, P6.2, R12.2, U8.30
/MATRIX_CS: JP1.4, P6.1, R10.2, U8.31
/MATRIX_DATA: P6.7, U8.11
/MATRIX_WR: P6.5, U8.10
/MISO: JP2.2, JP3.1, U5.7, U8.16
/MOSI: JP2.3, JP3.4, U3.5, U8.15
/RESET: C20.1, JP1.6, JP3.5, RESET.2, U8.29
/SCK: JP2.1, JP3.3, R7.2, U3.2, U8.17
/SCLK: U3.3, U5.5
/SD_CS: R5.2, U3.9, U8.14
/XM: JP5.1, P5.1, U8.23
/XP: JP5.3, P5.3, U8.25
/YM: JP5.4, P5.4, U8.26
/YP: JP5.2, P5.2, U8.24
GND: BT1.2, C1.2, C2.2, C3.2, C4.2, C5.2, C6.2, C7.1, C8.2, C10.2, C11.2, C12.2, C13.2, C14.2, C15.2, C16.2, C17.2, C18.2, C19.2, D2.2, D3.2, JP1.1, JP1.2, JP2.9, JP3.6, JP4.4, JP6.1, P1.2, P1.3, P2.5, P2.6, P2.7, P2.8, P2.9, P6.8, P6.11, P6.13, P6.15, RESET.1, RV1.3, U1.1, U2.7, U3.1, U3.4, U3.7, U3.10, U4.4, U5.6, U5.G1, U5.G2, U5.G3, U5.G4, U6.5, U6.6, U6.7, U6.8, U6.9, U6.10, U6.11, U6.12, U6.13, U7.1, U8.3, U8.5, U8.21, U9.6, U9.16, X1.2
unnamed: BT1.1, U6.14
unnamed: C7.2, R3.2, U2.6
unnamed: C8.1, R4.1, RV1.1
unnamed: C9.1, U4.1, U4.2, U4.6, U4.7
unnamed: C9.2, JP6.2
unnamed: C10.1, D1.2, U7.3
unnamed: C13.1, U8.20
unnamed: C14.1, F1.1, P2.1
unnamed: C15.1, P2.2, R8.1
unnamed: C16.1, P2.3, R9.1
unnamed: C20.2, R13.2, U10.3
unnamed: D1.1, P1.1
unnamed: D2.1, R6.2
unnamed: D3.1, R7.1
unnamed: D4.1, R15.1
unnamed: D4.2, U9.10
unnamed: D5.1, R14.1
unnamed: D5.2, U9.17
unnamed: R4.2, U2.8
unnamed: R8.2, U9.12
unnamed: R9.2, U9.11
unnamed: R10.1, U9.20
unnamed: R11.2, U9.1, U10.2
unnamed: R12.1, U9.4
unnamed: RV1.2, U4.3, U4.5
unnamed: U8.7, X1.1
unnamed: U8.8, X1.3
VCC: C5.1, C6.1, C19.1, JP4.3, R11.1, U1.3, U3.14, U5.4, U9.3, U9.13, U9.14, U10.1

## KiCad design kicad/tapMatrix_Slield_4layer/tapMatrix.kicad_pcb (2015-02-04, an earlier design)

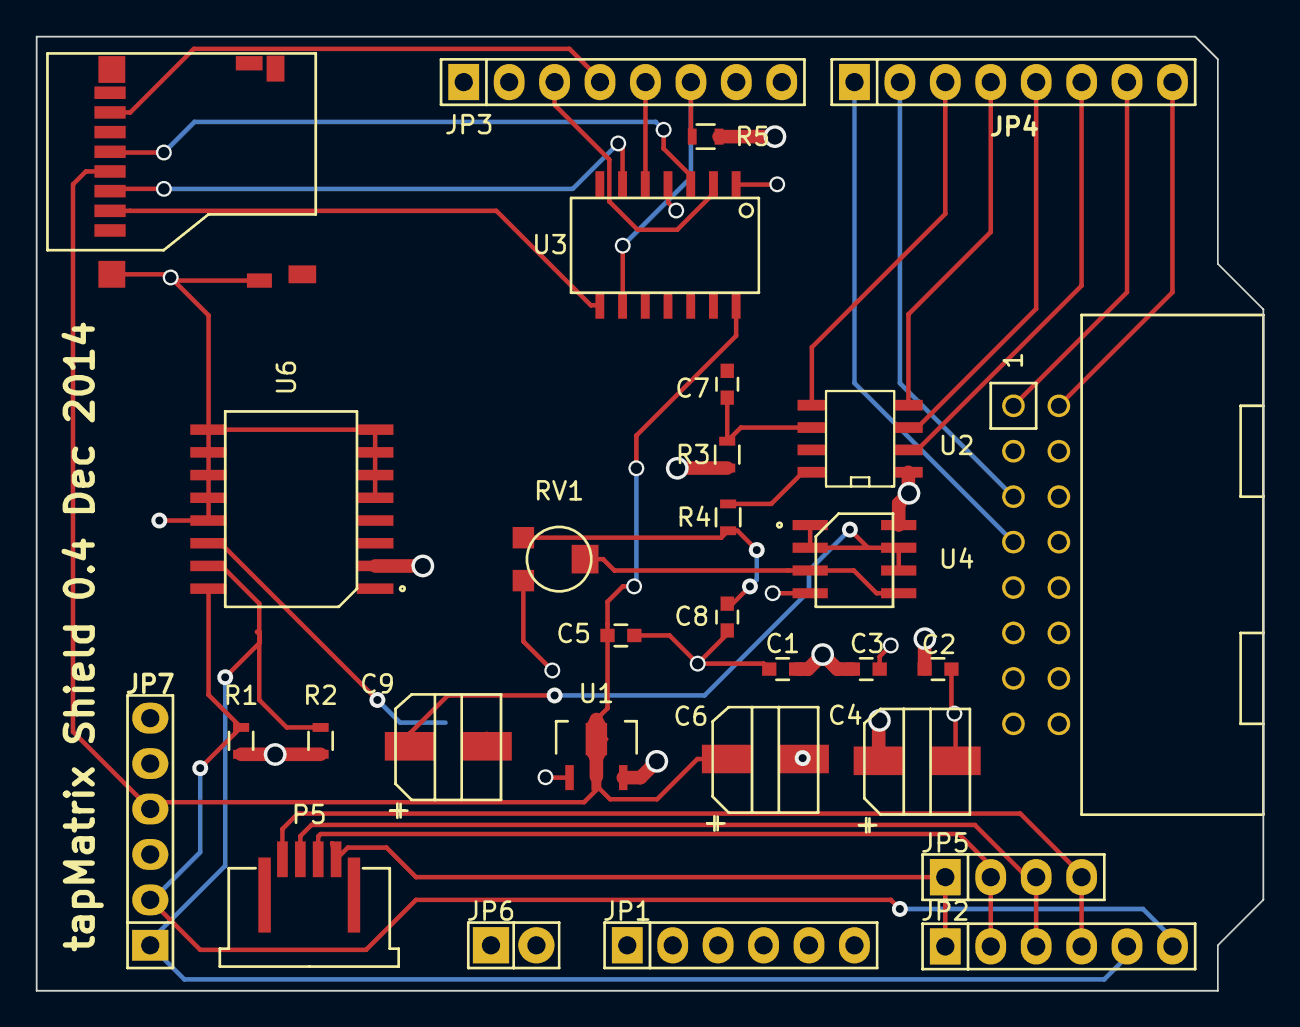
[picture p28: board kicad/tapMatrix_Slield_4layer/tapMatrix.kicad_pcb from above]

Board: 4 copper layers, 68.6 x 53.3 mm, 31 parts (1 on the bottom side), 31 nets.

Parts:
BT1: BATTERY; CR2032
C1, C2, C3, C5, C7: 0.1uF; C_0603
C4, C6, C9: 100uF/6V; EEE-0JA101WR
C8: 0.01uF; C_0603
JP1: 6_PIN_1; Pin_Header_Straight_1x06
JP2: 6_PIN_2; Pin_Header_Straight_1x06
JP3: 8_PIN_1; Pin_Header_Straight_1x08
JP4: 8_PIN_2; Pin_Header_Straight_1x08
JP5: 4_PIN_1; Pin_Header_Straight_1x04
JP6: SPKR; Pin_Header_Straight_1x02
JP7: 6_PIN_3; Pin_Header_Straight_1x06
P5: P5; SFW4R­5STE1LF
P6: LED_MATRIX_HDR; 5103310­-3
R1, R2: R; R_0603
R3: 100K; R_0603
R4: 1.5K; R_0603
R5: 10K; R_0603
RV1: POT; TC33X
U1: MCP1700T-3302E/MB; SOT89-3_Housing
U2: MCP4921-E/SN; SOIC-8_N
U3: 74LS125; SO-14
U4: TS922; TS922_SO8
U5: SD_CARD; 114-00841-68
U6: DS3231

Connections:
+3.3V: C5.1, C6.1, JP7.4, U1.2, U3.14, U5.4
+5V: C1.1, C2.1, C3.1, C4.1, JP1.3, JP7.3, P6.12, P6.14, P6.16, R1.1, R2.1, R3.1, R5.1, U1.3, U2.1, U4.8, U6.2
/CS: U3.8, U5.2
/DAC_CS: JP4.6, U2.2
/DAC_DI: JP4.4, U2.4
/DAC_LAT: JP4.3, U2.5
/DAC_SCK: JP4.5, U2.3
/DATA_IN: U3.6, U5.3
/I2C_SCL: JP2.6, JP7.2, R1.2, U6.16
/I2C_SDA: JP2.5, JP7.1, R2.2, U6.15
/MATRIX_CLK: JP4.8, P6.2
/MATRIX_CS: JP4.7, P6.1
/MATRIX_DATA: JP4.1, P6.7
/MATRIX_WR: JP4.2, P6.5
/MISO: JP3.4, U5.7
/MOSI: JP3.5, U3.5
/SCK: JP3.3, U3.2
/SCLK: U3.3, U5.5
/SD_CS: JP3.6, R5.2, U3.9
/XM: JP2.1, JP5.1, P5.1
/XP: JP2.3, JP5.3, P5.3
/YM: JP2.4, JP5.4, P5.4
/YP: JP2.2, JP5.2, P5.2
GND: BT1.2, C1.2, C2.2, C3.2, C4.2, C5.2, C6.2, C7.1, C8.2, JP1.4, JP1.5, JP3.2, JP6.1, JP7.5, JP7.6, P6.8, P6.11, P6.13, P6.15, RV1.3, U1.1, U2.7, U3.1, U3.4, U3.7, U3.10, U4.4, U5.6, U5.G1, U5.G2, U5.G3, U5.G4, U6.5, U6.6, U6.7, U6.8, U6.9, U6.10, U6.11, U6.12, U6.13
unnamed: BT1.1, U6.14
unnamed: C7.2, R3.2, U2.6
unnamed: C8.1, R4.1, RV1.1
unnamed: C9.1, U4.1, U4.2, U4.6, U4.7
unnamed: C9.2, JP6.2
unnamed: R4.2, U2.8
unnamed: RV1.2, U4.3, U4.5

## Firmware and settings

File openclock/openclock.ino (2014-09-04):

/*
 openclock.ino
 
 An open hardware, Ardunio powered, touchscreen controlled, large display, multicolor 
 LED matrix alarm clock. Intuitive design, adaptive color and brightness, and easy 
 to see and use with uncorrected vision.
 
 Sure Electronics DP14112 bicolor 16x32 LED display
 * 7 - DATA
 * 6 - WR
 * 0 - CLK
 * 1 - CS
 * +5V
 * GND
 
 N010-0554-T048 Fujitsu touch panel
 * A0 - XM
 * A1 - YP
 * A2 - XP
 * A3 - YM
 
 Chronodot v2.1 DS3231SN Real Time Clock
 * A4 - I2C SDA
 * A5 - I2C SCL
 * +3.3V
 * GND
 
 Adafruit WaveShield
 * 2, 3, 4, 5 - DAC
 * 10 - SD card
 * 13, 12, 11 - SD card
 
 
 Craig Bonsignore
 http://clock.bonsignore.com
 http://github.com/cbonsig/openclock
 
 */


// 7 may 2012 . change digits to red at night . move pin 4 to 0 . move pin 5 to 1
// 22 may 2012 . change from bold to normal font during sleeping hours
// 16 june 2012 . map touchscreen press to pixels
// 30 june 2012 . recalibrate for new enclosure
// 17 nov 2012 . rename to openclock.ino and manage revisions using github
// 24 nov 2012 . move contributed libraries to sketch folder, per Arduino 1.0.2 guidance
//             + major refactoring . created currentTime subroutine 
//             + all characters now defined by global variables
//             + all characters drawn to screen in one place @ end of main loop()
// 02 dec 2012 . more refactoring . debugging new tap detection
// 03 dec 2012 . fix hour bug introduced yesterday 
// 03 dec 2012 . tap detection virtual buttons: hr+/- min+/- ampm message
// 04 dec 2012 . fix bug: midnight renders as 0:00
// 09 dec 2012 . addeded disfunctional proto-alarm-set-mode
// 16 dec 2012 . replaced <Chronodot.h> with Arduino Time Library
//               to-do: improve tap/button management, time variables,
//               alarm variables, and menu logic. try to use similar logic
//               and code as alphaclockfive
// 04 feb 2013 . reworked logic in detectTap and menuMode to improve alarm setting
//               now more functional, but not quite right. menu timer doesn't reset.
//               improved comments in a few places
// 02 mar 2013 . major rewrite for menu/tap timers
// 03 mar 2013 . debug . reworked menu . tbd -- rewrite rendering for menu states
// 04 mar 2013 . rough code for menu scheme complete -- tbd: RTC commits, fix time set
// 05 mar 2013 . debug . display logic refinement
// 07 mar 2013 . various fixes . added on/off for alarm . fixed colors . added RTC commit for time
//               added : between hour and minute for alarm display
// 08 mar 2013 . fixed year/month/day date set rendrering . fixed set time/date 0:00 bug (i think)
// 11 mar 2013 . improved commenting
//               tbd: commit alarm to RTC or EEPROM?
//                    add wave board for and alarm trigger code
//                    perhaps 12h / 24 h mode
// 15 mar 2013 . 1371 bytes free ... 1377 ... 1378 ... 1382 .. 1392 ... 1395 ... 1403
//               add PROGMEM, reduce char[] size, replace int with byte for displaystate, 
//               eliminate dispHour / dispMinute / etc
//               move dot and pixel out of global . changed region, pixel to byte
//               move touchscreen object from global to function
//               with 1403 bytes free, #include <WaveHC.h> drops freeRam to 162
//               adding any of the WaveHC objects causes complete failure 
//
//               modify WaveHC.h to trick it into thinking this is aa ATMega168
//               #include <WaveHC.h> now freeRam = 674
//               SdReader object -> freeRam = 662
//               FatVolume object -> freeRam = 631
//               FarReader root object -> freeRam = 612
//               FatReader file object -> freeRam = 593
//               WaveHC wave object -> freeRam = 576
//               Add helper functions -> freeRam = 576
//               Add playcompete("1.WAV") in setup{} -> freeRam = 570 ... still no audio :(
//                   but clock does function!
// 16 mar 2013 . added setup{} functions for Waveshield, and added test audio triggered upon
//               selecting "EXIT" in menu. Audio works! FreeRam = 558, still OK

// LIBRARIES
#include <Time.h>         // The Arduino Time library, http://www.arduino.cc/playground/Code/Time
#include <DS1307RTC.h>    // For optional RTC module. (This library included with the Arduino Time library)
#include <Wire.h>         // Standard I2C library for Chronodot
#include "ht1632c.h"      // http://code.google.com/p/ht1632c/
#include <TouchScreen.h>  // https://github.com/adafruit/Touch-Screen-Library
#include <WaveHC.h>       // https://code.google.com/p/wavehc/
#include <WaveUtil.h>     // WaveHC.h is modified to think its running on ATmega168

// LED MATRIX OBJECT
ht1632c ledMatrix = ht1632c(&PORTD, 7, 6, 0, 1, GEOM_32x16, 2); 

// TOUCHSCREEN PINS
// For this orientation, the N010-0554-T048 Fujitsu touch panel is oriented with the touch film side up
// and the ribbon to the left. The four wires, from top to bottom, correspond to XM, YP, XP, YM
#define XM A0             // black.  must be an analog pin, use "An" notation!
#define YP A1             // green.  must be an analog pin, use "An" notation!
#define XP A2             // yellow. can be a digital pin
#define YM A3             // blue.   can be a digital pin

// TOUCHSCREEN CALIBRATION
// determined by trial and error for touch panel and Sure Electronics DP14112 
#define XCAL_LEFT   75    // X touchscreen reading corresponding to pixel column 0
#define XCAL_RIGHT  930   // X touchscreen reading corresponding to pixel column 31
#define YCAL_TOP    300   // Y touchscreen reading corresponding to pixel row 0
#define YCAL_BOTTOM 770   // Y touchscreen reading corresponding to pixel row 15

// WAVESHIELD OBJECTS
SdReader card;            // This object holds the information for the card
FatVolume vol;            // This holds the information for the partition on the card
FatReader root;           // This holds the information for the volumes root directory
FatReader file;           // This object represent the WAV file for a pi digit or period
WaveHC wave;              // This is the only wave (audio) object, since we will only play one at a time
#define error(msg) error_P(PSTR(msg)) // Define macro to put error messages in flash memory

// TIMER VARIABLES
unsigned long menuStartMillis;
unsigned long tapStartMillis;
int PROGMEM menuTimeout = 10000; // 10 second timeout for menu
byte PROGMEM tapTimeout = 250; // 0.25 second timeout for tap event

// define hour at which clock digits change from red to green in morning
#define GREEN_HOUR      7

// define tapZone "button" numbers
#define TAP_NONE        0
#define TAP_HOURPLUS    1
#define TAP_HOURMINUS   2
#define TAP_MINUTEPLUS  3
#define TAP_MINUTEMINUS 4
#define TAP_AMPM        5
#define TAP_MESSAGE     6
#define TAP_WTF         7
int tapZone = TAP_NONE;

// define tapCenter "button" numbers
#define TAP_CENTER      8
byte tapCenter = TAP_NONE;
boolean tapNew = false;

// define alarm states
#define ALARM_OFF      0
#define ALARM_SET      1
#define ALARM_ACTIVE   2
#define ALARM_SNOOZE   3
byte alarmState = ALARM_OFF;

// define display states
#define STATE_DISP_TIME  0
#define STATE_DISP_DATE  1
#define STATE_ALARM_INIT  2
#define STATE_ALARM_SET  21
#define STATE_TIME_INIT  5
#define STATE_TIME_SET  51
#define STATE_DATE_INIT  6
#define STATE_DATE_YEAR  61
#define STATE_DATE_MONTH  62
#define STATE_DATE_DAY  63
#define STATE_EXIT  99

// define render options
#define RENDER_NONE 0
#define RENDER_OFF 1
#define RENDER_ON 2

byte displayState = STATE_DISP_TIME;  // 0 if in normal mode, 1+ for menu choices

byte menuTaps = 0;  // number of taps since menu was last activated

boolean tapActive = false; // true if screen has been taped in last tapTimeout (0.5) seconds, else false
boolean menuActive = false; // true while menu is active

// initialize colors    
byte digit_color = GREEN;
byte message_color = RED;
byte ampm_color = GREEN;

// initialize values for each character on display
//   ---------------------------------------------------------
//  |                                                         |
//  |    dig[1]      dig[2]      :      dig[3]      dig[4]    |
//  |                                                         |
//  | msg[1] msg[2] msg[3] msg[4] msg[5] msg[6] msg[7] msg[8] |
//   ---------------------------------------------------------

char dig[5]  = "0123";
char msg[9] = "01234567";

// variables for the current time
byte nowHour12 = 0;
byte nowHour24 = 0;
byte nowMinute = 0;
byte nowPM = 0;

// variables for the alarm time
byte alarmHour12 = 7;
byte alarmHour24 = 7;
byte alarmMinute = 0;
byte alarmPM = 0;

// variables for new time/date when setting time
byte newHour12 = 0;
byte newHour24 = 0;
byte newMinute = 0;
byte newPM = 0;
int newYear = 2013;
byte newMonth = 1;
byte newDay = 1;


//////////////////////////////////////////////////////////////////////////////////
// setup()
// set the pins, initialize the display, etc.

void setup () {

  pinMode(7, OUTPUT);         // initialize ht1632c pin
  pinMode(6, OUTPUT);         // initialize ht1632c pin
  pinMode(0, OUTPUT);         // initialize ht1632c pin
  pinMode(1, OUTPUT);         // initialize ht1632c pin

  Wire.begin();               // initialize I2C
  setSyncProvider(RTC.get);   // the function to get the time from the RTC

  ledMatrix.clear();          // clear the display
  ledMatrix.pwm(5);           // set brightness (max=15)

  // the following line sets the RTC to the date & time this sketch was compiled
  //RTC.adjust(DateTime(__DATE__, __TIME__));

  if (!card.init()) {             //play with 8 MHz spi (default faster!)  
    error("Card init. failed!");  // Something went wrong, lets print out why
  }
  
  // enable optimize read - some cards may timeout. Disable if you're having problems
  card.partialBlockRead(true);

  // Now we will look for a FAT partition!
  uint8_t part;
  for (part = 0; part < 5; part++) {   // we have up to 5 slots to look in
    if (vol.init(card, part)) 
      break;                           // we found one, lets bail
  }
  if (part == 5) {                     // if we ended up not finding one  :(
    error("No valid FAT partition!");  // Something went wrong, lets print out why
  }
  
  // Try to open the root directory
  if (!root.openRoot(vol)) {
    error("Can't open root dir!");      // Something went wrong,
  }

  delay(100);
}

//////////////////////////////////////////////////////////////////////////////////
// loop()
// main program loop

void loop () {

  // read current time and set global variables for hour, minute, am/pm
  currentTime();                        

  // detect tap state
  detectTap();                          

  // act upon new tap and set new display state
  doActions();                           

  // change display state according to current menu mode
  setDisplay();                         

  // set color and brightness based on current time
  setStyle(nowHour24, nowMinute);     

  // set main screen rendering flag based on alarm state

  int renderOpt = RENDER_NONE;
  if ( alarmState >= ALARM_SET) renderOpt = RENDER_ON;
  else if (alarmState == ALARM_OFF ) renderOpt = RENDER_OFF;

  // call the relevant screen rendering function
  // based on the current display state

  if (displayState == STATE_DISP_TIME){
    renderTime(nowHour12, nowMinute, nowPM);
  }
  else if (displayState == STATE_DISP_DATE){
    renderOther(RENDER_NONE);
  }  
  else if (displayState == STATE_ALARM_INIT){
    renderOther(renderOpt);
  }
  else if (displayState == STATE_ALARM_SET){
    renderTime(alarmHour12, alarmMinute, alarmPM);
  }
  else if (displayState == STATE_TIME_INIT){
    renderOther(RENDER_NONE);
  }
  else if (displayState == STATE_TIME_SET){
    renderTime(newHour12, newMinute, newPM);
  }
  else if (displayState == STATE_DATE_INIT){
    renderOther(RENDER_NONE);
  }
  else if (displayState == STATE_DATE_YEAR){
    renderOther(RENDER_NONE);
  }
  else if (displayState == STATE_DATE_MONTH){
    renderOther(RENDER_NONE);
  }
  else if (displayState == STATE_DATE_DAY){
    renderOther(RENDER_NONE);
  }
  else if (displayState == STATE_EXIT){
    renderOther(RENDER_NONE);
  }
  
  // check on the alarm
  
  if (alarmState >= ALARM_SET) checkAlarm();
  
  // wait for a little while
  delay(50);
}

//////////////////////////////////////////////////////////////////////////////////
// currentTime()
// read the current time from the RTC
// set global variables: nowHour24, nowHour12, nowPM, nowMinute
// set dispHour24, dispHour12, dispMinute, dispPM to current time
// (if in menu mode, disp* variables will be overwritten before going to screen)

void currentTime () {

  // read the current time from the RTC   
  setSyncProvider(RTC.get);

  // set global variables for current time 
  nowHour24 = hour();
  if (nowHour24 > 12){
    nowHour12 = nowHour24 - 12;
    nowPM = 1;
  }
  else if (nowHour24 == 0){
    nowHour12 = 12;
    nowPM = 0;
  }
  else{
    nowHour12 = nowHour24;
    nowPM = 0;
  }

  if (nowHour24 == 12) nowPM = 1;   

  nowMinute = minute();

}

//////////////////////////////////////////////////////////////////////////////////
// detectTap()
// determine if the screen has been tapped in the last few milliseconds (timeout)
// and set the tapActive flag accordingly. If we're ready for a new tap, and 
// the pressure exceeds the tap threshold, the figure out where the screen
// is being tapped, and set the tapZone variable, which acts like a virtual
// button.

int detectTap(){

  // TOUCHSCREEN FUNCTION
  // Final parameter (90) is the resistance between X+ and X- in ohms
  TouchScreen ts = TouchScreen(XP, YP, XM, YM, 90);


  // initialize array to hold [x, y, prior_x, prior_y] data for tap location
  int dot[4] = {
    0,0,0,0      }; 

  // initialize array to hold mapped coordinates for tap location
  // pixel[0,1] = [x,y] pixel ... x=0-31, y=0-15
  byte pixel[2];


  int lastTapZone = tapZone;

  // if a tap is active, check the tap timer.
  // if the timer hasn't elapsed, don't bother to check for a new tap (debounce)
  // if the timer has elapsed, reset and return

  if (tapActive == true){
    if ((millis() - tapStartMillis) < tapTimeout){
      return lastTapZone;
    }
    else{
      tapActive = false;
      return TAP_NONE;
    }
  }

  // if we made it this far, we are ready to check for a new tap

  // read X,Y coordinates and pressure
  Point p = ts.getPoint();

  if (p.z < ts.pressureThreshhold ){   // touchscreen isn't being taped
    return lastTapZone;                // so don't change anything, and return 
  }

  // if we have made it this far...
  // the tap timer is not active, and the screen is being taped
  // so this is a new tap, and we have to figure out what "button" is pushed

  // define variables for screen regions
  byte verticalRegion = 0;
  byte horizontalRegion = 0;

  // map coordinates to pixel location
  pixel[0] = map(p.x,XCAL_LEFT,XCAL_RIGHT,0,31);           // x calibration by trial-and-error
  pixel[1] = map(p.y,YCAL_TOP,YCAL_BOTTOM,0,15);           // y calibration by trial-and-error

  byte px = pixel[0];
  byte py = pixel[1];

  // map pixel location to screen region
  if      (px >=0  && px <=8 )  horizontalRegion = 1;        // x pixel 0-8   = 1st digit of hour
  else if (px >=9  && px <=17)  horizontalRegion = 2;        // x pixel 9-17  = 2nd digit of hour
  else if (px >=18 && px <=25)  horizontalRegion = 3;        // x pixel 18-25 = 1st digit of minute
  else if (px >=26 && px <=33)  horizontalRegion = 4;        // x pixel 26-33 = 2nd digit of minute
  else                          horizontalRegion = 0;

  if      (py >=0  && py <=5 )  verticalRegion = 1;          // y pixel 0-5   = top of time digits
  else if (py >=6  && py <=10)  verticalRegion = 2;          // y pixel 6-10  = bottom of time digits
  else if (py >=11 && py <=16)  verticalRegion = 3;          // y pixel 11-16 = message / ampm area
  else                          verticalRegion = 0;

  // define new virtual button states based on region tapped

  if (verticalRegion == 1){
    if (horizontalRegion == 1) tapZone = TAP_HOURPLUS;
    if (horizontalRegion == 2) tapZone = TAP_HOURPLUS;
    if (horizontalRegion == 3) tapZone = TAP_MINUTEPLUS;
    if (horizontalRegion == 4) tapZone = TAP_MINUTEPLUS;
  }
  else if(verticalRegion == 2){
    if (horizontalRegion == 1) tapZone = TAP_HOURMINUS;
    if (horizontalRegion == 2) tapZone = TAP_HOURMINUS;
    if (horizontalRegion == 3) tapZone = TAP_MINUTEMINUS;
    if (horizontalRegion == 4) tapZone = TAP_MINUTEMINUS;
  }
  else if(verticalRegion == 3){
    if (horizontalRegion == 1) tapZone = TAP_MESSAGE;
    if (horizontalRegion == 2) tapZone = TAP_MESSAGE;
    if (horizontalRegion == 3) tapZone = TAP_MESSAGE;
    if (horizontalRegion == 4) tapZone = TAP_AMPM;
  }
  else if(verticalRegion == 0 || horizontalRegion == 0){
    tapZone = TAP_WTF;
  }
  else{
    tapZone = TAP_NONE;
  }

  // check if tap is in the middle, for toggling ON/OFF in alarm init screen
  if (verticalRegion == 1 || verticalRegion == 2){
    if (horizontalRegion == 2) tapCenter = TAP_CENTER;
    else if (horizontalRegion == 3) tapCenter = TAP_CENTER;
    else tapCenter = TAP_NONE;
  }
  else{
    tapCenter = TAP_NONE;
  }


  menuActive = true;                                      // set menuActive flag
  tapStartMillis = millis();                              // reset tap timer
  menuStartMillis = millis();                             // reset menu timer
  tapActive = true;                                       // tap event is active
  tapNew = true;                                          // this is a new tap
  menuTaps++;

  // just in case we're going to set the time, set new time/date variables 
  // according to the time that we entered the menu
  if ( menuTaps == 1 ){
    newHour12 = nowHour12;
    newHour24 = nowHour24;
    newMinute = nowMinute;
    newPM = nowPM;
    newYear = year(now());
    newMonth = month(now());
    newDay = day(now());
  }

  return tapZone;
}

//////////////////////////////////////////////////////////////////////////////////
// doActions()
// perform appropriate action to respond to a new tap on the screen
// depending on current display state, and location of tap
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

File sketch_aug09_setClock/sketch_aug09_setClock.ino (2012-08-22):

    // simple clock using 16x32 bicolor LED matrix, Chronodot, and Arduino
    // craig bonsignore
    // 15 april 2012
    // 7 may 2012 . move pin 4 to 0 . move pin 5 to 1


    #include <Wire.h>
    #include <ht1632c.h> // http://code.google.com/p/ht1632c/
    #include <Chronodot.h> // http://planetstephanie.net/2011/12/01/chronodot-library-update/
    
    ht1632c ledMatrix = ht1632c(&PORTD, 7, 6, 4, 5, GEOM_32x16, 2); // initialize the 16x32 display
    Chronodot RTC; // initialize the Chronodot real time clock
    
    void setup () {
    
      Wire.begin();
      RTC.begin();
    
      if (! RTC.isrunning()) {
        // Serial.println("RTC is NOT running!");
      }      
      
      ledMatrix.clear(); // clear the display
      ledMatrix.pwm(15); // set brightness (max=15)
      ledMatrix.setfont(FONT_4x6); // use a 6x13 bold font
      
      // the following line sets the RTC to the date & time this sketch was compiled
      RTC.adjust(DateTime(__DATE__, __TIME__));
      
    }
    
    void loop(){
    
      ledMatrix.putchar(0,0,'!',RED,6);
      ledMatrix.sendframe();
    
    }
    

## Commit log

2012-08-22 Add Solidworks parts and assembly
    [28pdipskt.SLDPRT, 3in_speaker.SLDPRT, 3x2-100.SLDPRT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]
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2012-12-03 Update openclock/openclock.ino
    Added a link to an explanation about why using a pin higher than 8 does not work.
    [openclock.ino]
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2012-12-04 ix bug: midnight renders as 0:00
    [openclock.ino]
2012-12-04 Revert "ix bug: midnight renders as 0:00"
    This reverts commit d720b7c31345ddba16c0d397b14fbf2bdf63aabc.
    [openclock.ino]
2012-12-04 Revert "Revert "ix bug: midnight renders as 0:00""
    This reverts commit 11733e3db17b308eef8b654cf0011cb639cfc867.
    [openclock.ino]
2012-12-17 Replace <Chronodot.h> with Arduino Time Library
    Swapped out Chronodot library for the Arduino Time Library to be more
    standardized. Auto-formatted to fix indent levels.
    [openclock.ino]
2013-02-05 reworked touch and menu functions
    improved functionality of alarm setting mode. Not quite prefected.
    Menu timer isn't resetting for some reason.
    [openclock.ino]
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2013-02-27 UI design refinements
    Mock-ups of menu modes, and draft additions to flow chart
    [open_clock_menu_examples.xlsx]
2013-03-03 major rewrite for menu/tap timers
    [open_clock_menu_examples.xlsx]
2013-03-04 Debug + Rearrange menus
    Halfway implemented new menu scheme. TBD: revise display rendering for
    display states.
    [open_clock_menu_examples.xlsx]
2013-03-05 Rough code for menu scheme completed
    Rough code for menu scheme completed. TBD: code RTC commits for alarm
    and time; fix handling of time set.
    [openclock.ino]
2013-03-08 fix alarm color display, fix incrementation for am/pm
    [openclock.ino]
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2013-03-09 Fix date setting screens, add alarm on/off toggle
    [openclock.ino]
2013-03-10 Revert byte to int for tapZone and displayState to fix time set bug
    [openclock.ino]
2013-03-12 Fix set year display bug (20-1)
    Revert newYear from byte to int
    [openclock.ino]
2013-03-12 fix alarm color rendering on main screen
    [openclock.ino]
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2013-03-31 Correct year display
    Fix display of year for case where year = 2000 (default year for new
    chronodot)
    [openclock.ino]
2013-04-10 Created folders for 3D enclosure and 2D enclosure designs
    Moved OpenClockSolidworks to enclosure_design/3D_rev1 and created
    enclosure_design/2D_rev1 with Inkscape, LibreCAD, and SolidWorks files
    [28pdipskt.SLDPRT, 3in_speaker.SLDPRT, 3x2-100.SLDPRT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]
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2013-05-03 2d rev 2 curved enclosure, solidworks in progress
    [2D_Enclosure_Rev2.SLDPRT]
2013-05-04 Curved 2D Enclosure - Solidworks
    complete solidworks geometry for rev2 enclosure
    [2D_Enclosure_Rev2.SLDPRT, 2D_Enclosure_Rev2_Curved.DXF, 2D_Enclosure_Rev2_Curved.SLDDRW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]
2013-05-05 Updates to Solidworks enclosure design
    [2D_Enclosure_Rev2_Curved.DXF, 2D_Enclosure_Rev2_Curved.SLDDRW]
2013-05-05 Enclosure Design
    Curved enclosure design in Solidworks + Inkscape
    [28pdipskt.SLDPRT, 3in_speaker.SLDPRT, 3x2-100.SLDPRT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]
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2014-08-17 Initial commit for KiCad project and empty schematic
    [tapMatrix.sch]
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2014-08-18 Added ZIF socket, created component library, fixed Arduino headers
    [tapMatrix.sch]
2014-08-19 add led matrix header, microsd component, update libraries
    [tapMatrix.sch]
2014-08-20 improved headers, replaced global labels with local labels
    [tapMatrix.sch]
2014-08-21 confirm and revise quad-buffer and microsd schematic details
    [tapMatrix.sch]
2014-08-22 add 3.3V power supply, DAC, AMP, and Speaker Out
    [tapMatrix.sch]
2014-08-23 add real time clock to schematic
    [tapMatrix.sch]
2014-08-24 schematic edits to resolve error checking messages
    [tapMatrix.sch]
2014-08-25 added footprints for battery and ribbon sockets
    [$tapMatrix.sch, tapMatrix.kicad_pcb]
2014-08-25 created power and signal netclasses, updated design rules for oshpark
    [$tapMatrix.sch, tapMatrix.kicad_pcb, tapMatrix.sch]
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2014-08-29 complete first attempt at routing
    [tapMatrix.kicad_pcb]
2014-08-29 removed volume pot; created gerber files
    [tapMatrix-B_Cu.gbl, tapMatrix-B_Mask.gbs, tapMatrix-B_SilkS.gbo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]
2014-09-02 replaced 100uF caps with avail footprint; moved vias; revised to 0.2;
    [$tapMatrix.sch, tapMatrix.kicad_pcb]
2014-09-04 added optional 4-pin header as alt for touchscreen zif
    [$tapMatrix.sch, tapMatrix.kicad_pcb, tapMatrix.sch]
2014-09-04 create gerbers for shield v0.2
    [tapMatrix-B_Cu.gbl, tapMatrix-B_Mask.gbs, tapMatrix-B_SilkS.gbo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]
2014-09-04 replace voltage regulator with corrected component
    [tapMatrix.csv, tapMatrix.kicad_pcb, tapMatrix.sch]
2014-09-04 update gerbers for revision to voltage regulator component
    [tapMatrix-B_Cu.gbl, tapMatrix-B_Mask.gbs, tapMatrix-B_SilkS.gbo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]
2014-09-04 add top and bottom solder paste layers to gerbers
    [tapMatrix-B_Cu.gbl, tapMatrix-B_Mask.gbs, tapMatrix-B_Paste.gbp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]
2014-09-23 create v0.3_ fix problems with U1, U3, U4 components U1 used the wrong footprint. changed from SOT-23 to SOT-89-3 U3 used the narrow version of SOIC-14 (incorrectly named in library as SOIC-14_W). ch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
    [tapMatrix.csv, tapMatrix.kicad_pcb, tapMatrix.sch]
2014-10-27 Revised r0.3 components, tore up pcb
    [tapMatrix.kicad_pcb, tapMatrix.sch]
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2014-10-28 catch up with commits for moving R and C to tapmatrix library
    [tapMatrix.kicad_pcb]
2014-10-28 move pin header footprints to tapmatrix library
    [tapMatrix.kicad_pcb]
2014-10-28 move SOT-89-3 footprint to tapmatrix library
    [tapMatrix.kicad_pcb]
2014-10-28 moved SOIC footprints to tapmatrix library
    [tapMatrix.kicad_pcb]
2014-10-31 confirmed and revised IC footprints
    [tapMatrix.kicad_pcb]
2014-11-01 route v3 pcb, first draft
    [tapMatrix.kicad_pcb]
2014-11-01 resolved DRC errors in v0.3 layout
    [tapMatrix.kicad_pcb]
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2014-11-02 create gerbers for v0.3
    [tapMatrix-B_Cu.gbl, tapMatrix-B_Mask.gbs, tapMatrix-B_SilkS.gbo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]
2014-11-02 revised layout to improve GND and +5V plane connectivity
    [tapMatrix-B_Cu.gbl, tapMatrix-B_Mask.gbs, tapMatrix-B_SilkS.gbo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]
2014-11-02 added paste files to gerbers for stencil. updated dwg revision date.
    [tapMatrix-B_Cu.gbl, tapMatrix-B_Mask.gbs, tapMatrix-B_Paste.gbp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]
2014-11-03 revised C3 to link to tapMatrix library, other minor edits
    re-routed C3
    repositioned reference labels for caps
    changed U1 line width to be consistent with other components
    [tapMatrix-B_Cu.gbl, tapMatrix-B_Mask.gbs, tapMatrix-B_Paste.gbp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]
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2014-11-03 corrected uSD connector footprint
    [tapMatrix.kicad_pcb]
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2014-11-24 corrected error with U1 pins (2 and 3 were reversed)
    [tapMatrix.kicad_pcb, tapMatrix.sch]
2014-11-24 corrected JP4, where MATRIX_WR and MATRIX_DATA were reveresed
    [tapMatrix-B_Cu.gbl, tapMatrix-B_Mask.gbs, tapMatrix-B_Paste.gbp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]
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2014-12-16 Add comment regarding RTC fix
    [openclock_shield0_3.ino]
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2014-12-24 Schematic: replaced RTC and added pot replaced DS1207 with DS3231 real time clock added potentiometer to amplifier circuit
    [tapMatrix.sch]
2014-12-25 add footprints and headers, tear up layout
    [tapMatrix.kicad_pcb, tapMatrix.sch]
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2015-01-05 Create Gerbers for 0.4
    [tapMatrix-B_Cu.gbl, tapMatrix-B_Mask.gbs, tapMatrix-B_Paste.gbp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]
2015-02-04 Correct reversed pins 2+3 on LDO
    Input and output pins were reversed on the MCP1703 voltage regulator.
    Corrected schematic, footprint, and layout.
    [tapMatrix.kicad_pcb, tapMatrix.sch]
2015-02-04 draft 4-layer version of board
    [tapMatrix-B_Cu.gbl, tapMatrix-B_Mask.gbs, tapMatrix-B_Paste.gbp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]
2015-02-14 0.4.1 revision - new level shifter component, etc
    Replace quad buffer / level shifter with 74AHC125N components tolerant
    of VCC=3.3V. Correct mixed pins on LDO. Add labels for breakout pins,
    and refine silkscreen text.
    [tapMatrix-B_Cu.gbl, tapMatrix-B_Mask.gbs, tapMatrix-B_Paste.gbp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]
2015-02-19 Start rev 0.5 board
    [tapMatrix-B_Cu.gbl, tapMatrix-B_Mask.gbs, tapMatrix-B_Paste.gbp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]
2015-02-20 complete first draft of 0.5 board
    add headers for FTDI, I2C, other extra pins.
    [tapMatrix.sch]
2015-02-21 Add ICSP header and power LED
    [tapMatrix.sch]
2015-03-17 Add FTDI USB-UART
    Added schematics for FTDI, based on Sparkfun Redboard and FTDI
    reference schematics. Created symbols for FT231XS and 2N7002PW.
    [tapMatrix.sch]
2015-03-17 Revised schematic for FTDI
    [tapMatrix.sch]
2015-03-31 Add SPI header for nRF8001
    [tapMatrix.sch]
2015-03-31 Datasheets + Footprints for 5V supply circuit
    [tapMatrix.sch]
2015-04-01 Datasheets + Footprints for AT328p, XTAL, Fuse, USB, FTDI
    [tapMatrix.sch]
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

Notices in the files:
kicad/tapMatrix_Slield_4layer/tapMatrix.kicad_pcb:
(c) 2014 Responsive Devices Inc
